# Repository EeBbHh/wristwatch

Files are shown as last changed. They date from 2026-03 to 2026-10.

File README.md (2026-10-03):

Disclaimer. This is a work in progress. Open source proof of concept provided. Screenshots and video provided. Documentation is subject to change.

NOTICE! Due to memory limits a second python file was created. sprites.py is required. Place next to code.py in the CIRCUITPY drive. The follwing lines need to be added to boot.py: "import displayio" and below that "displayio.release_displays()"

Clock + Metronome + Tuner wristwatch is the goal of this project. In addition. There are standalone files for each mode.

Dev Enviornment: Mu https://codewith.mu/en/, KiCAD https://www.kicad.org/

Circuitpython for QTpy RP2040: https://circuitpython.org/board/adafruit_qtpy_rp2040/

Circuitpython 10.x libraries: https://circuitpython.org/libraries

NOTE: Place the following in the lib folder: adafruit_bus_device folder, adafruit_display_text folder, adafruit_gc9a01a.mpy and adafruit_ticks.mpy. 

NOTE: Add the following to the requirements folder: adafruit_bus_device folder, adafruit_display_text folder and adafruit_gc9a01a folder.

Microcontroller: QTpy RP2040 https://www.adafruit.com/product/4900

Special thanks to these two projects that got me started on this journey. https://projecthub.arduino.cc/petbump10/arduino-tick-tock-metronome-a49188 and https://github.com/FoamyGuy/Adafruit_CircuitPython_Display_AnalogClock

Prototype 1, 2 and 3 Display: 1.28" Round TFT https://www.adafruit.com/product/6178 

Prototype 1 hardware: EYESPI BFF https://www.adafruit.com/product/5772, IoT Button BFF https://www.adafruit.com/product/5666, Vibration Mini Motor https://www.adafruit.com/product/1201, Piezo Buzzer https://www.adafruit.com/product/1740, LIPO Charger BFF https://www.adafruit.com/product/5397, 400mAh LIPO Battery https://www.adafruit.com/product/3898

Prototype 2 hardware: IoT Button BFF removed. Prototype board added. SMD parts replace THT parts. All SMD parts purchsed from https://www.digikey.com/ Buttons added. Piezo replaced with magnetic transducer. Schematic and board file provided. 

Prototype 3 hardware: EYESPI BFF removed. Prototype board updated. SMD FPC added. SMD vibration motor replaces THT vibration motor. 420mAh LIPO battery https://www.adafruit.com/product/4236 replaces 400mAh LIPO battery. 

Prototype 4 hardware: Prototype board updated. New 1.28 Display https://www.buydisplay.com/1-28-inch-tft-lcd-display-240x240-round-circle-screen-for-smart-watch, SMD FPC updated. QTpy dock added. Futher refinement is underway as I put protoboardV4 through testing.

Prototype 5 hardware: Circuit for display reset added. Circuit for backlight added. QTpy dock adjusted from 17.5mm to 18mm. Prototype board version 5 sits at 25mm. 

Prototype 6 hardware: Lipo BFF circuitry absorbed to further reduce height of the stack. Side actuated buttons replaced top actuated buttons but might try other types.  Final iteration for 6 will have the female headers removed and vibration motor moved out of the way for soldering the QTpy closer to the board. Prototype board version 6 sits at 11.30mm. Goal is to get closer to 13 with case.

Prototype 7 hardware: TBD

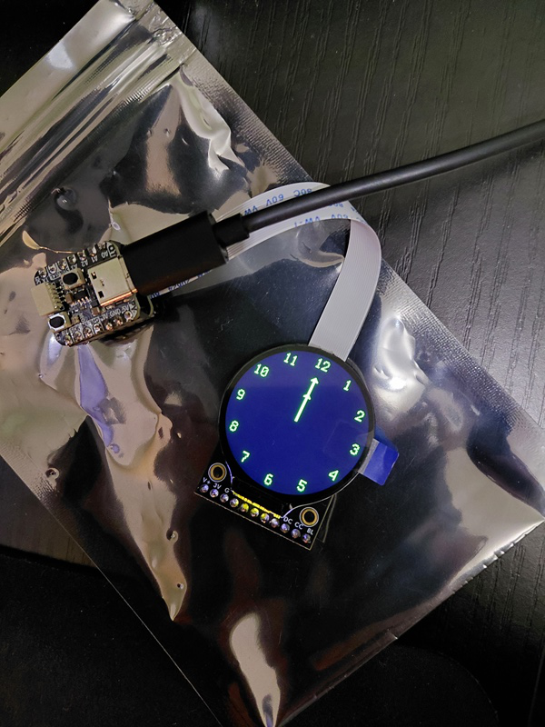
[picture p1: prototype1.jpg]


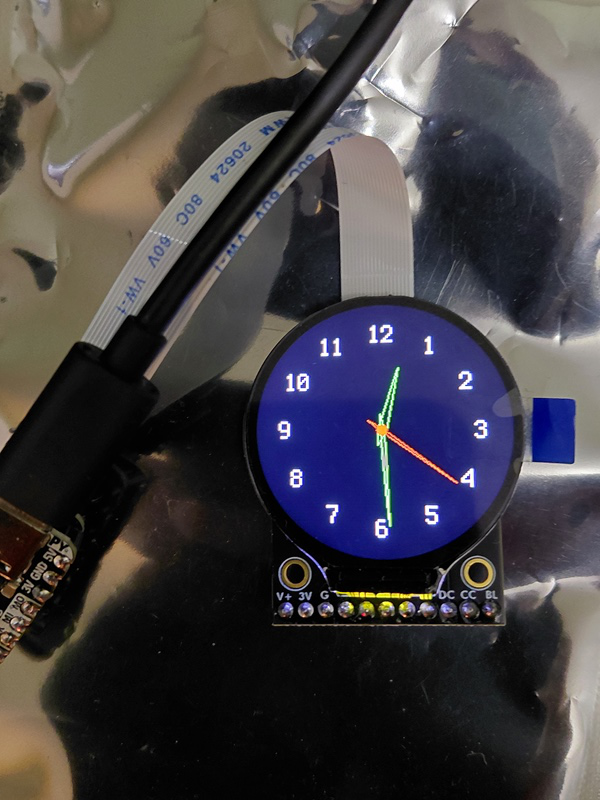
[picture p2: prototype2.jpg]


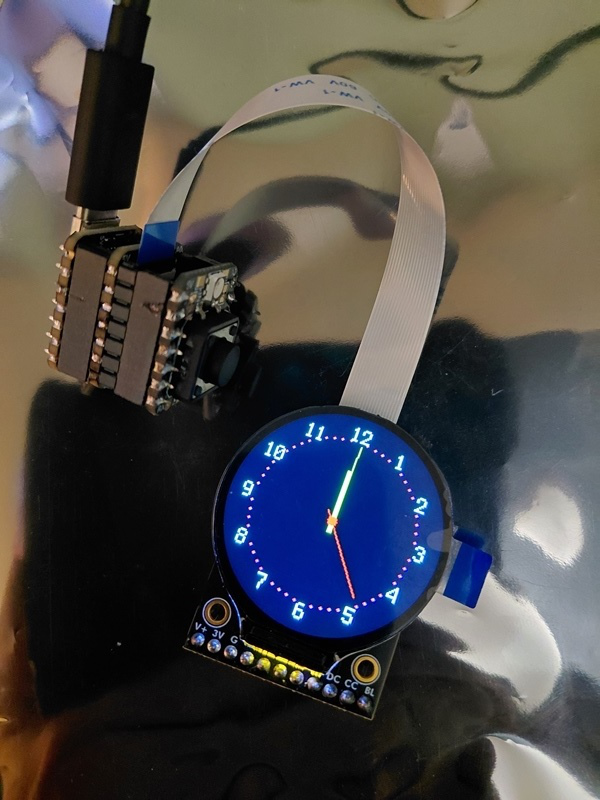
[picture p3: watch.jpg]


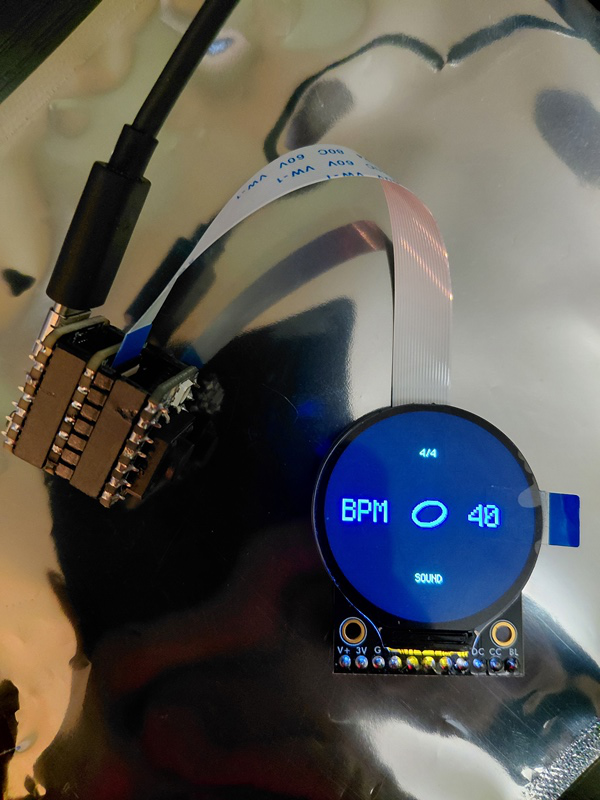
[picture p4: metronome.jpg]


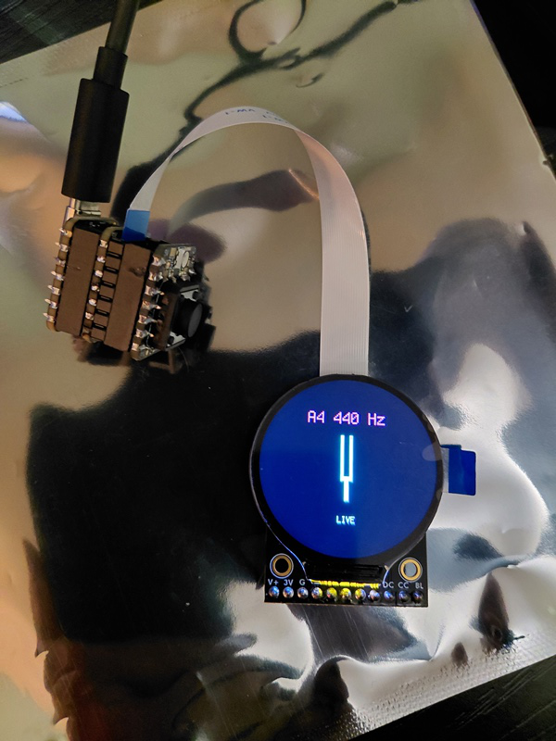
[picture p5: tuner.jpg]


https://github.com/user-attachments/assets/00a04122-98c7-4e2a-a195-a43d13c6c467

Vibration circuit layout. A transistor and resistor are used to make it possible for the QTpy to control the motor with 3 volts. A diode is used as a flyback for when the motor stops running. The transistor connects to the black wire, the resistor and the diode. The black wire goes from the emitter lead of the transistor to ground. The resistor(100ohm) connects the base lead of the transistor to A1. The anode portion of the diode connects to the collector lead of the transistor. The cathode porton of the diode connects to the red wire. The red wire connects to 3.3 volts. The driver motor connects to each side of the diode. Blue to anode and red to cathode. 

Component list: 100Ω resistor, diode(1N4007) and transistor(2N2222)

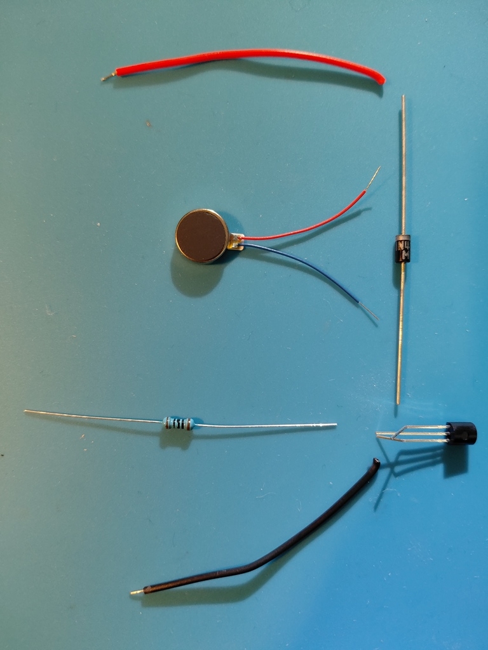
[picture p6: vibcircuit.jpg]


Soldered vibration circuit.

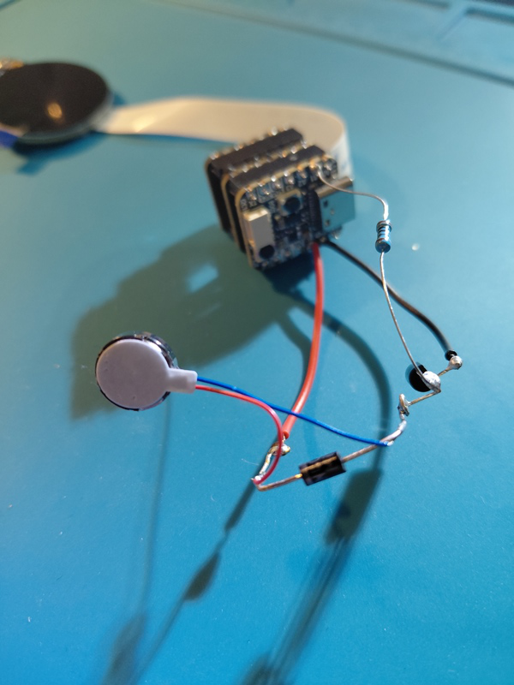
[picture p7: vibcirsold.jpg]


https://github.com/user-attachments/assets/0c229e03-611d-4f90-9194-24d2ad153cdb

Soldered piezo.

https://github.com/user-attachments/assets/ea14efcf-dfc6-47f1-8c45-b138b7211cc2

LIPO BFF added. Backlight hack added(red wire at the top) to allow for screen dimming as a battery saving feature.

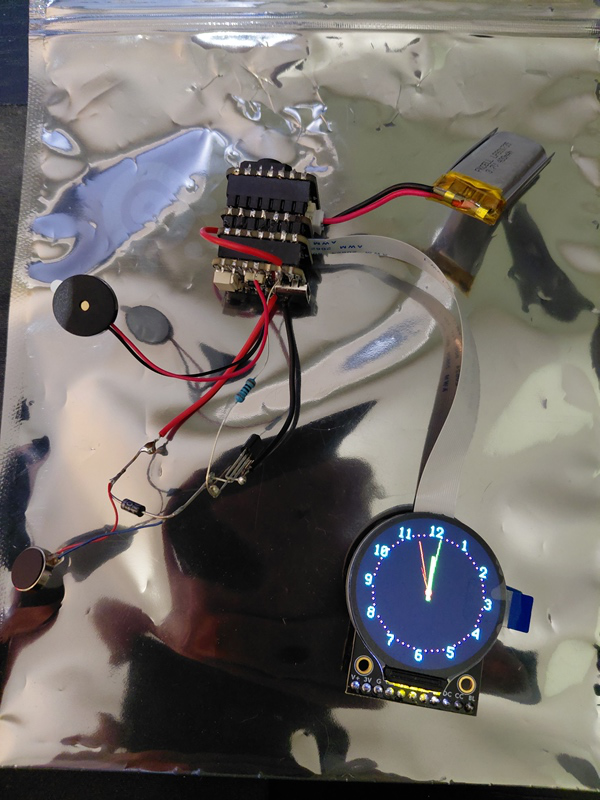
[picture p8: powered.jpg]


Screen dimming test. At the 10 second mark the screen dims.

https://github.com/user-attachments/assets/76fc044c-b8f3-486a-8c0e-50453308a22c

Prototype 2 board screenshots. Pre and post solder.

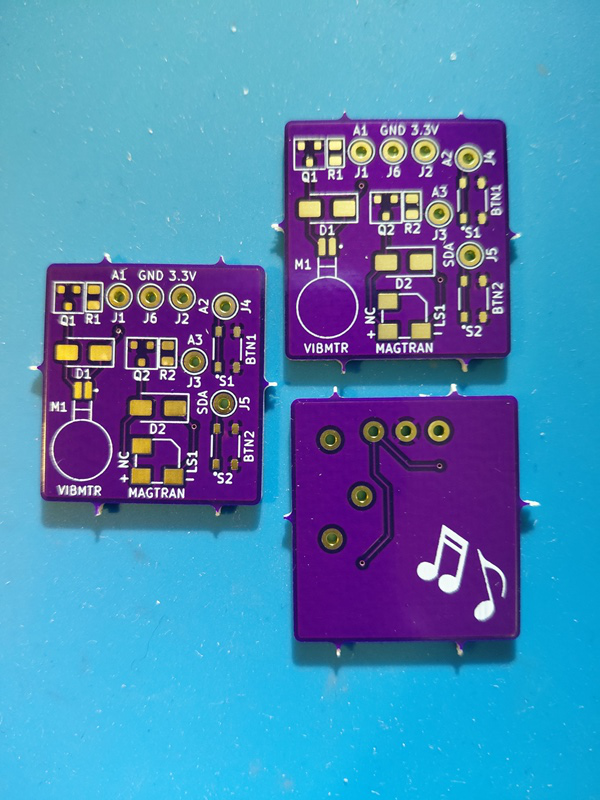
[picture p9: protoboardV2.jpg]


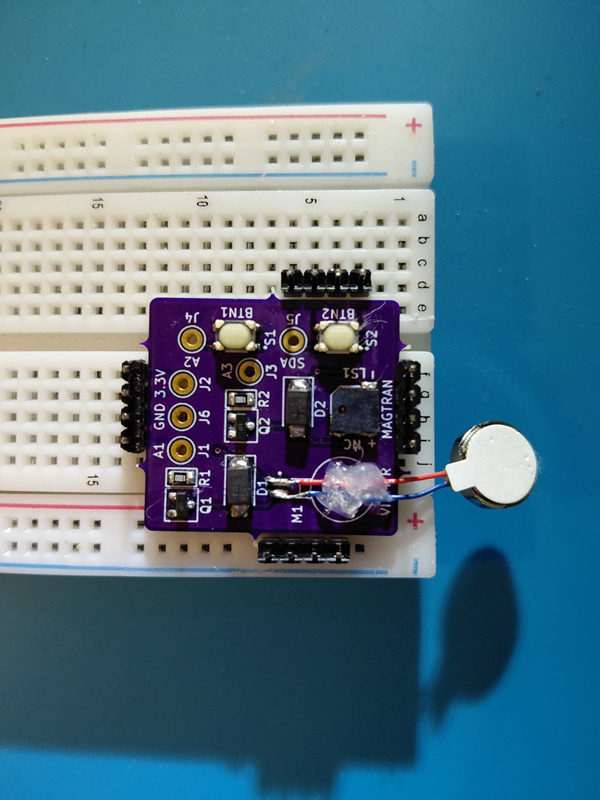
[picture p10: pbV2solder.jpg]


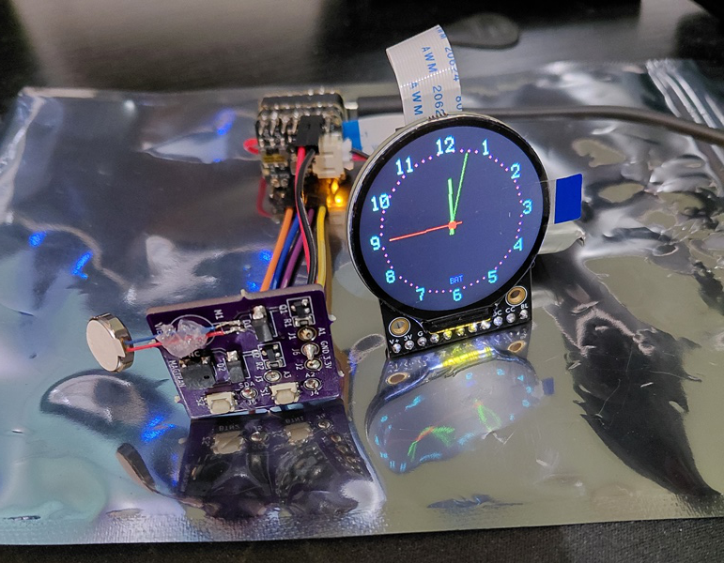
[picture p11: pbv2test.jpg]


Prototype 3 board screenshots. Pre and post solder.

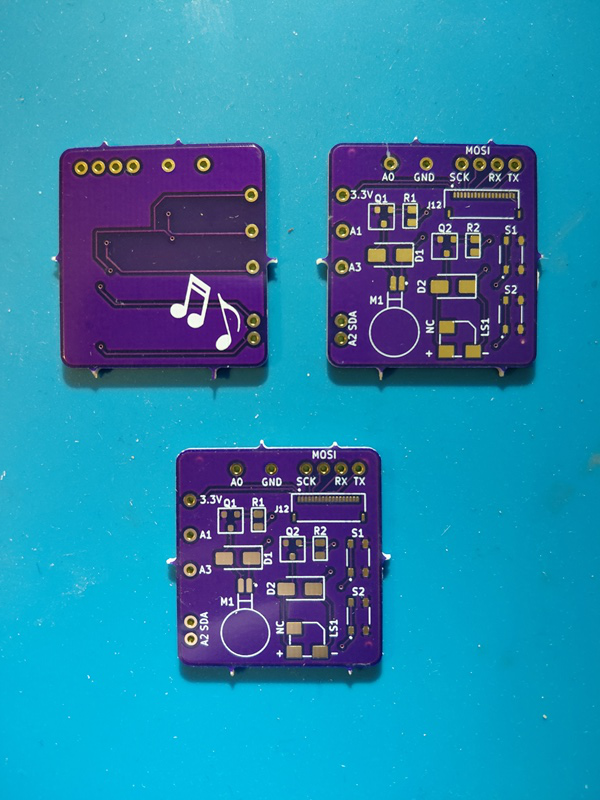
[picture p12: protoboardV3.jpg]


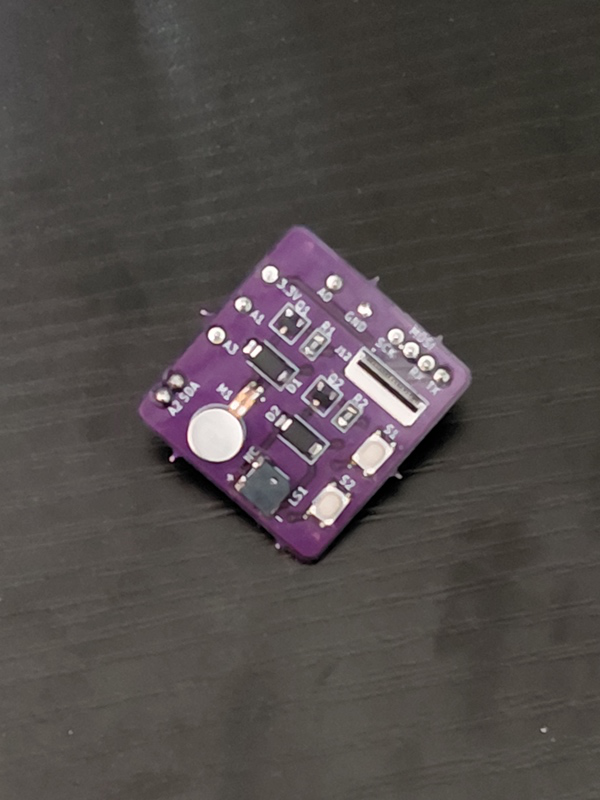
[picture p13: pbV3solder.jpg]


Prototype 4a board screenshots. Pre and post solder.

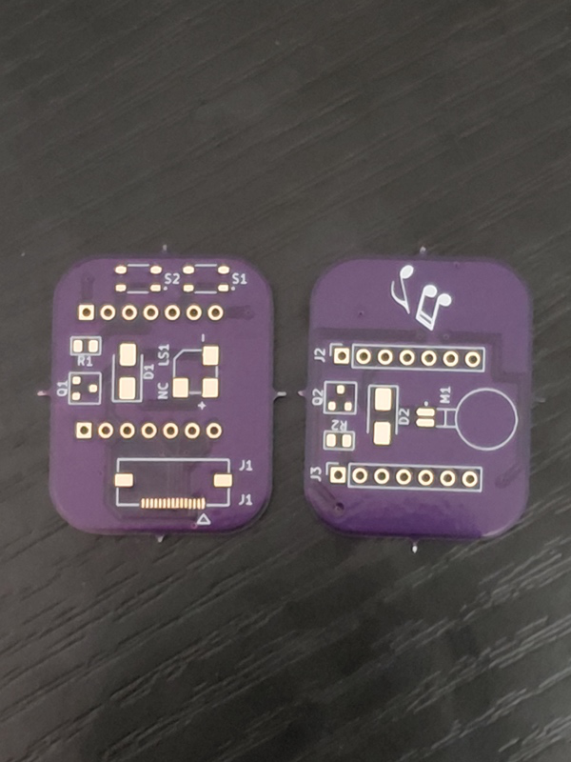
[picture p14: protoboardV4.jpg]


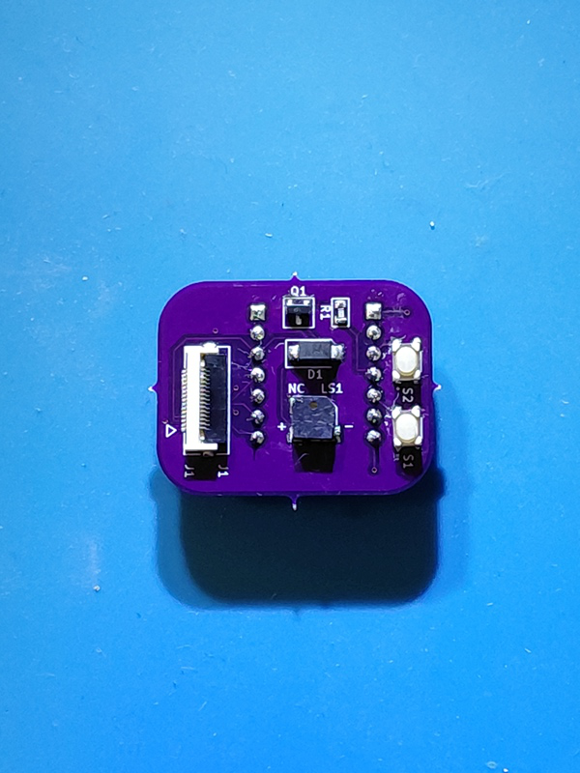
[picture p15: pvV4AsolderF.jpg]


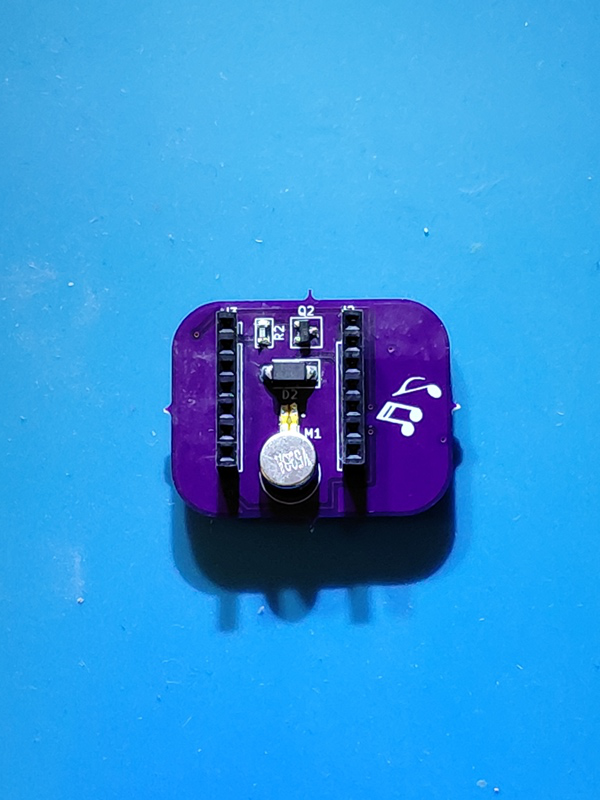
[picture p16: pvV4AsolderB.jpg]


Prototype 5a board screenshots. Pre and post solder.

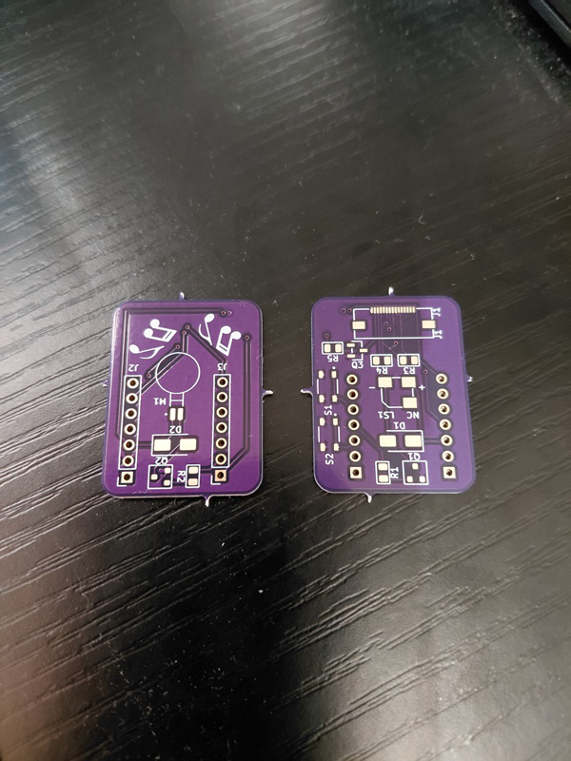
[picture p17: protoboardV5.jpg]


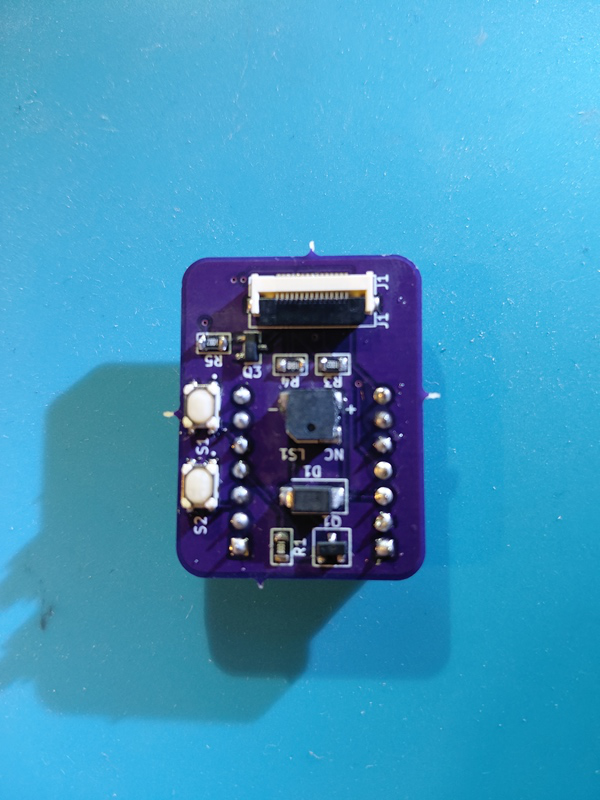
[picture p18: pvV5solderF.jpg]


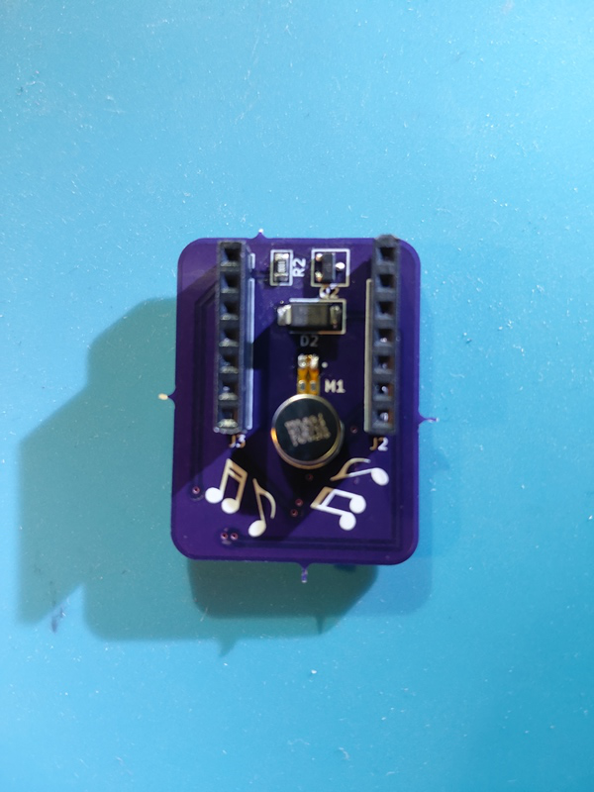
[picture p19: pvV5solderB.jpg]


Prototype 5b board screenshots. Pre and post solder.

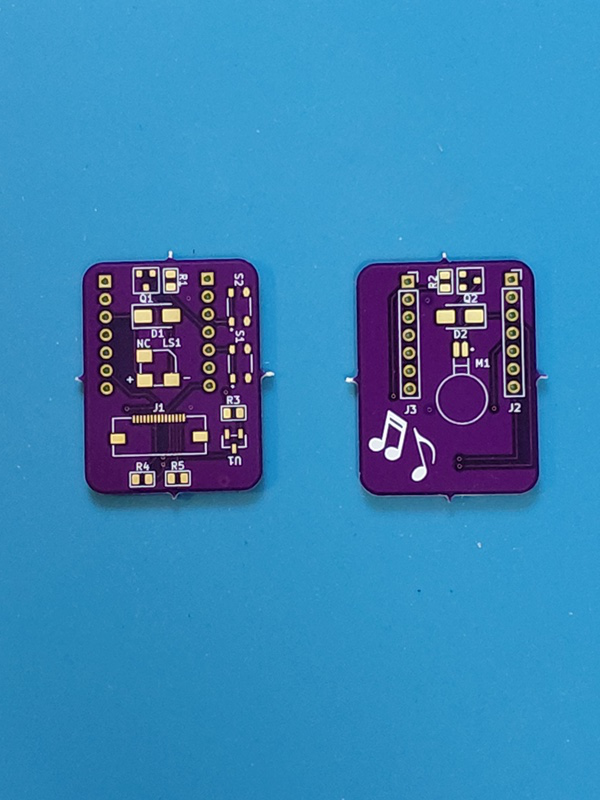
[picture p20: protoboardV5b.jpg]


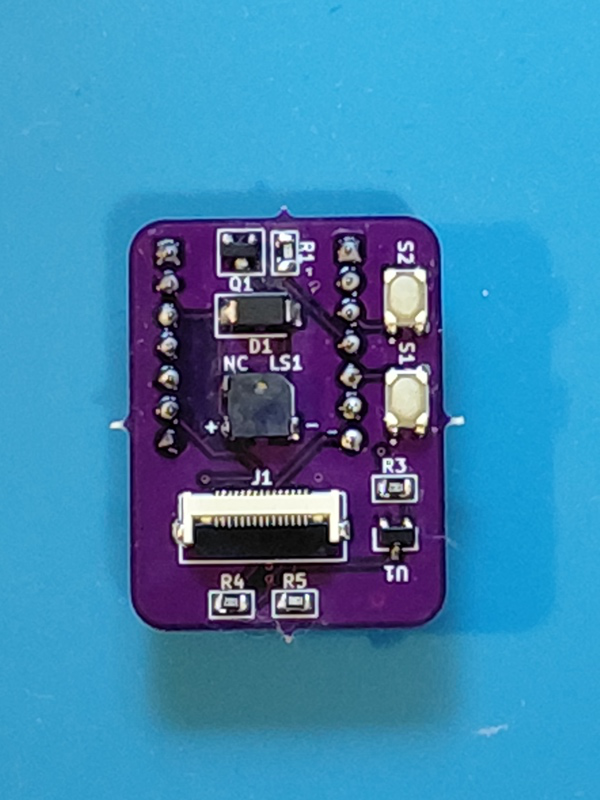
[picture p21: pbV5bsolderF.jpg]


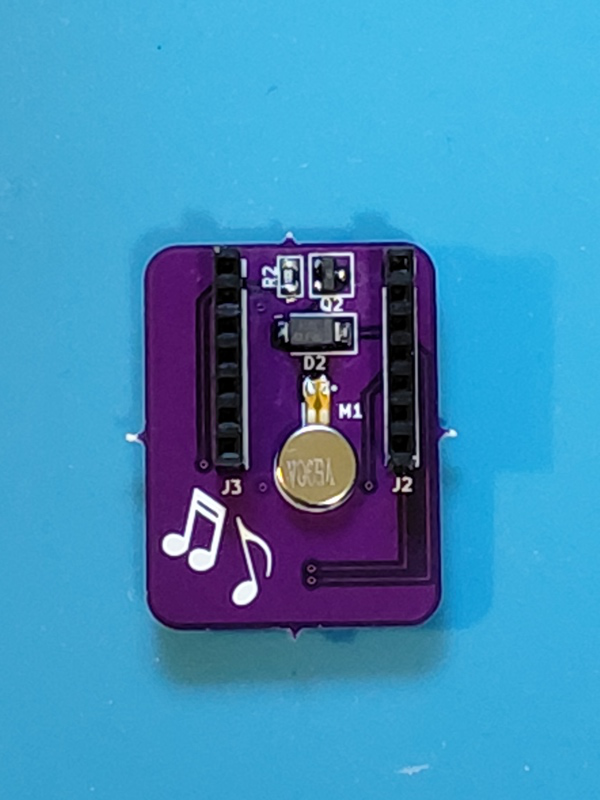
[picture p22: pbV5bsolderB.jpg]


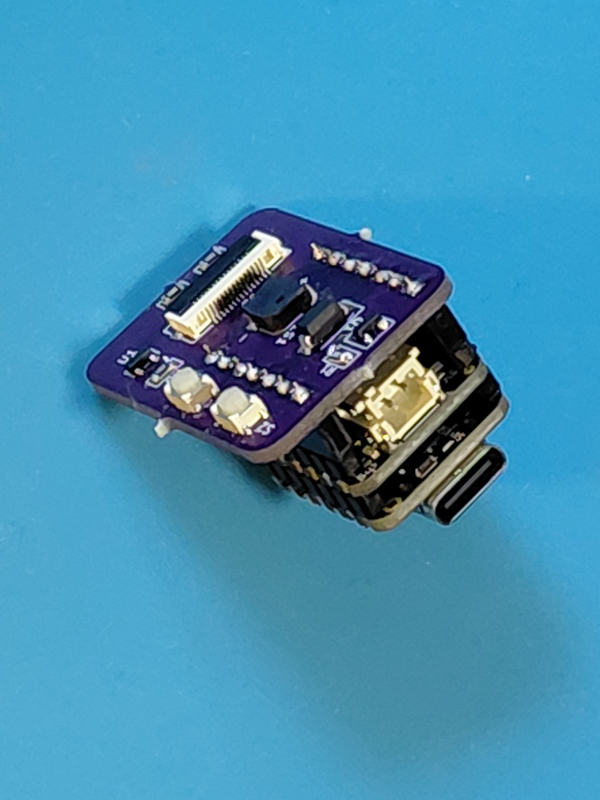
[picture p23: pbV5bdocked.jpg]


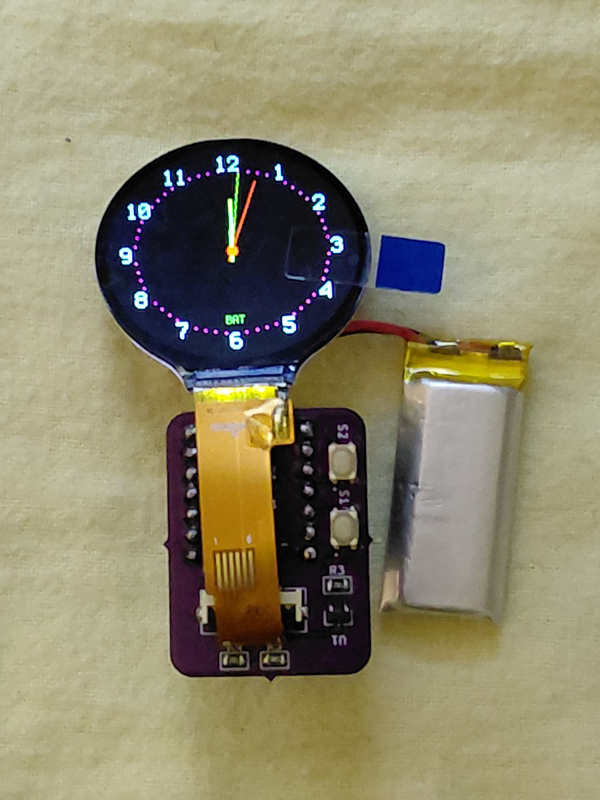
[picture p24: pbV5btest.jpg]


Prototype 6a board screenshots. Pre and post solder.

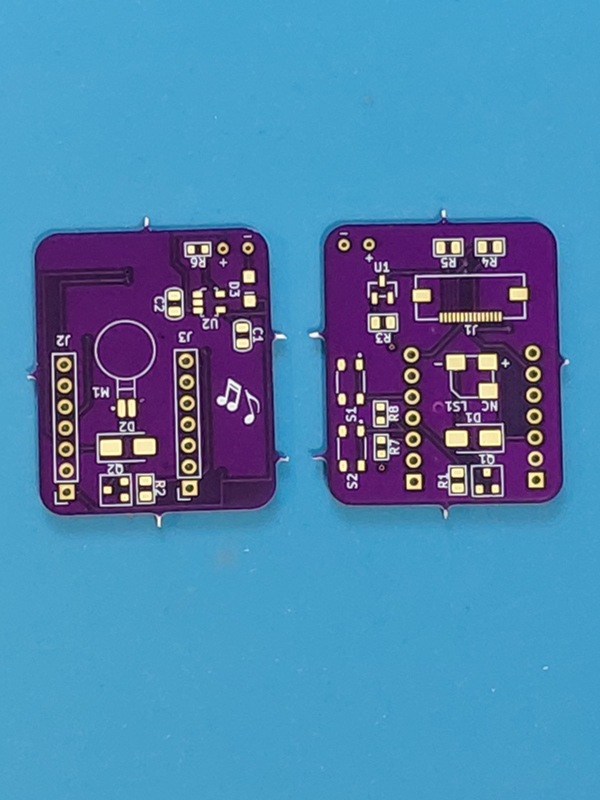
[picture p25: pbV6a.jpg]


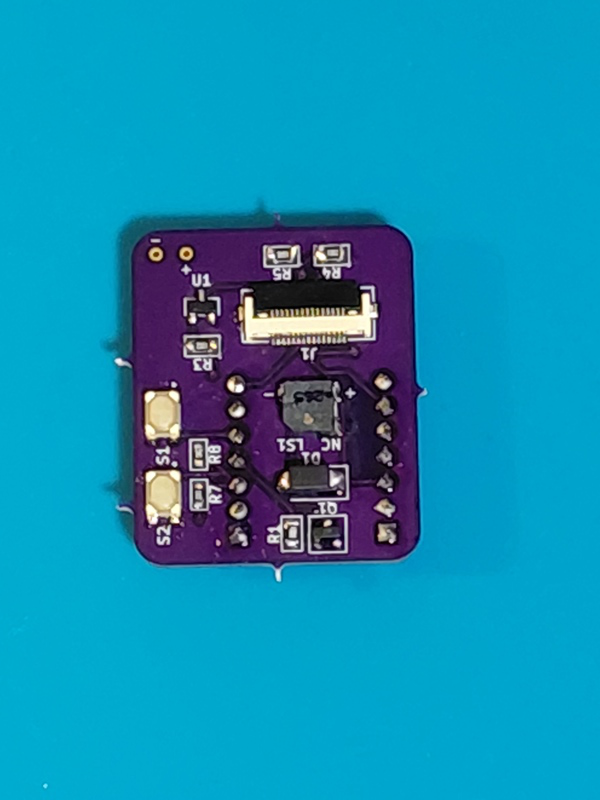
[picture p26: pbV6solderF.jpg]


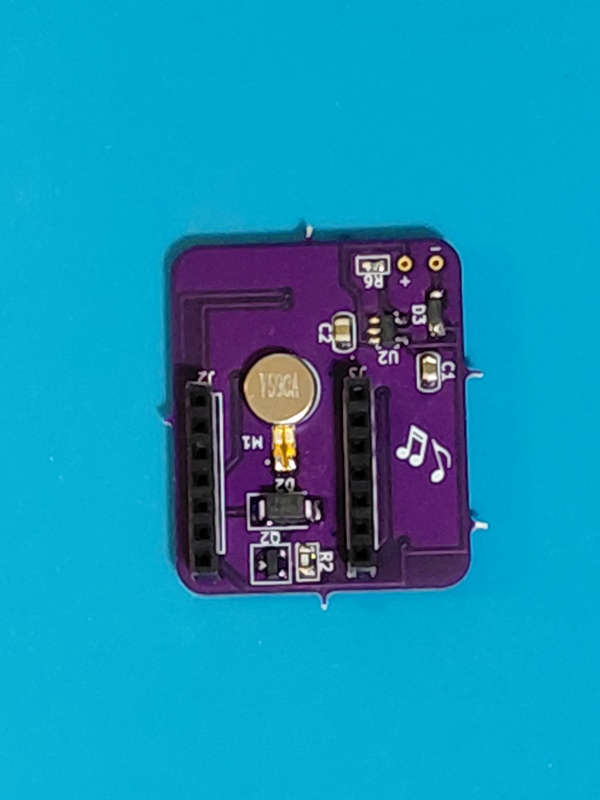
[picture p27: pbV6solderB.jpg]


Prototype 6b board screenshots. Pre and post solder.

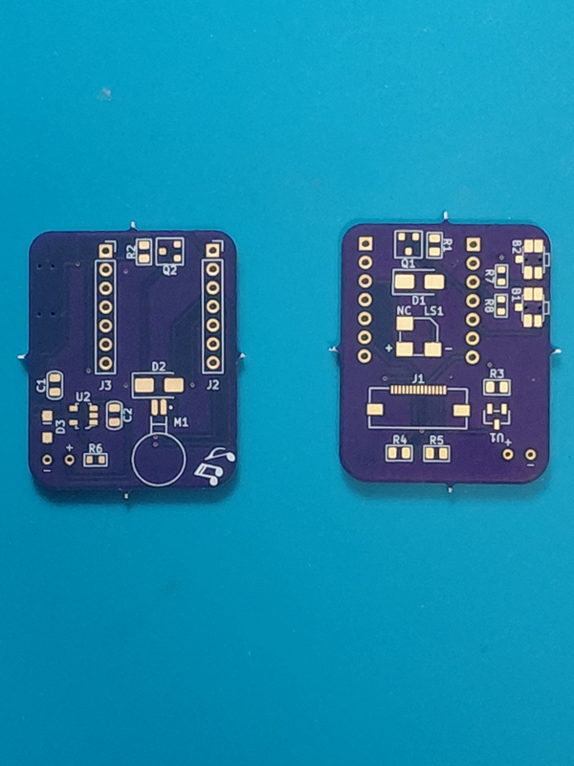
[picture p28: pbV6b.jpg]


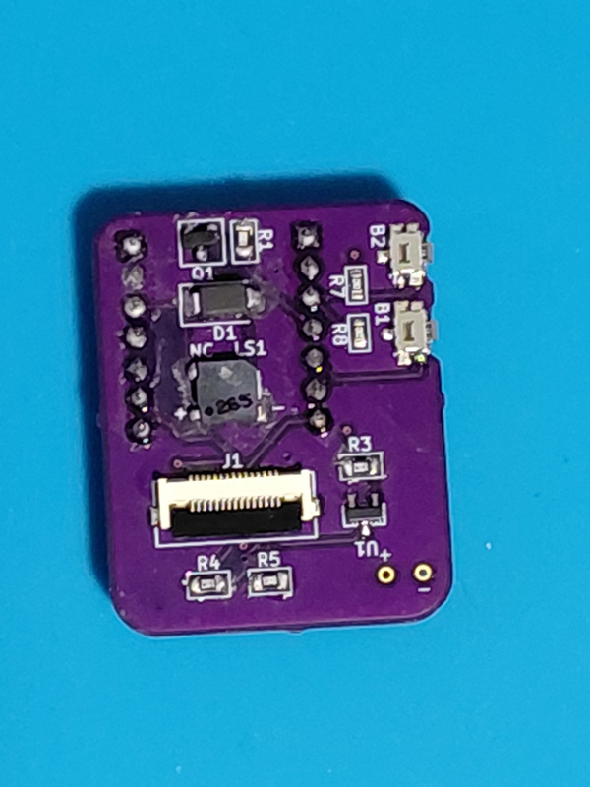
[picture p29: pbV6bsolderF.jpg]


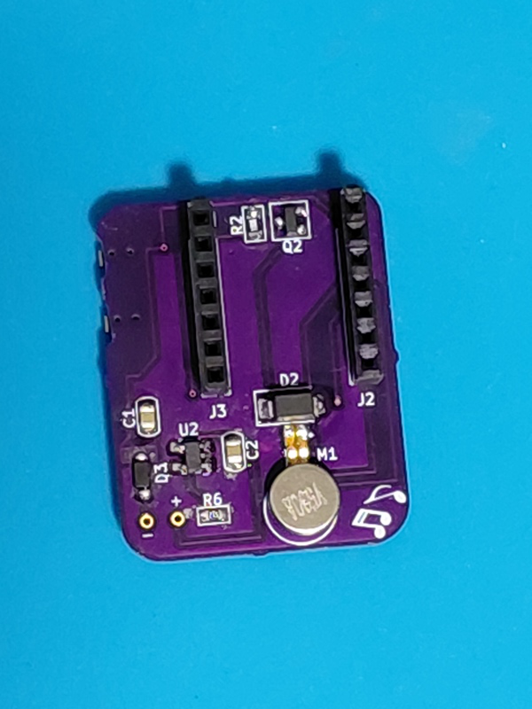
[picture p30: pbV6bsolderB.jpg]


Prototype 6c board screenshots. Pre and post solder.

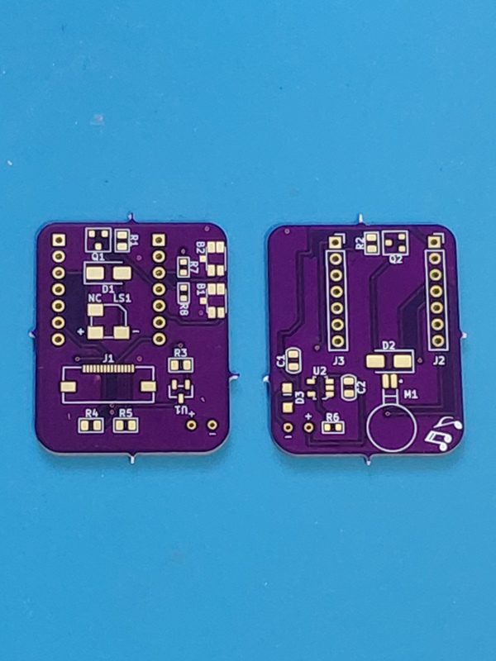
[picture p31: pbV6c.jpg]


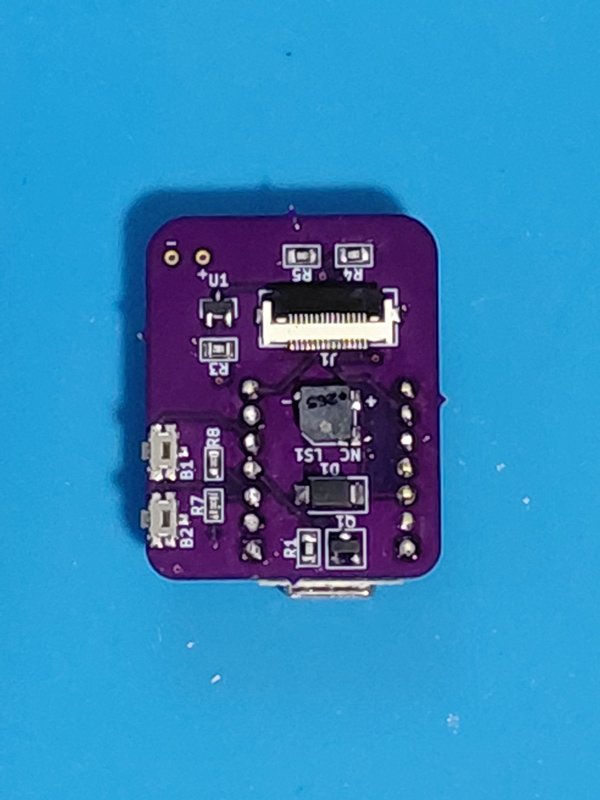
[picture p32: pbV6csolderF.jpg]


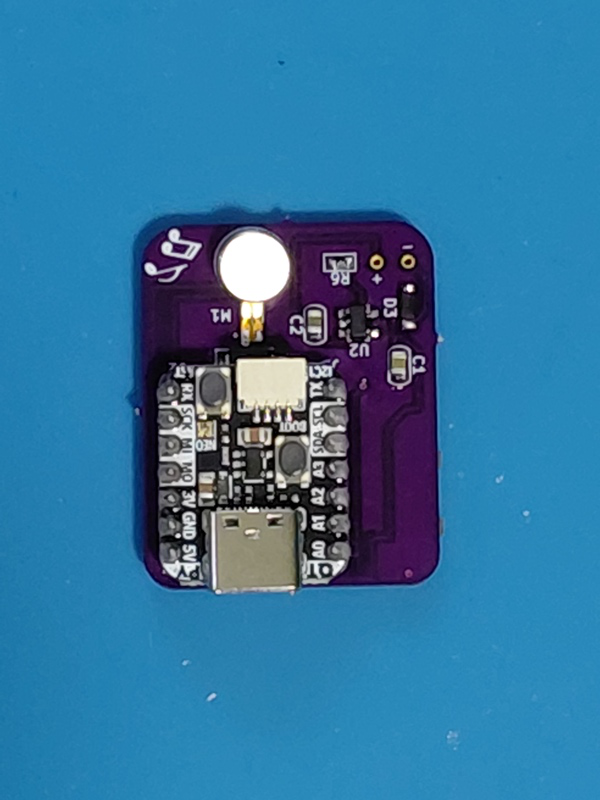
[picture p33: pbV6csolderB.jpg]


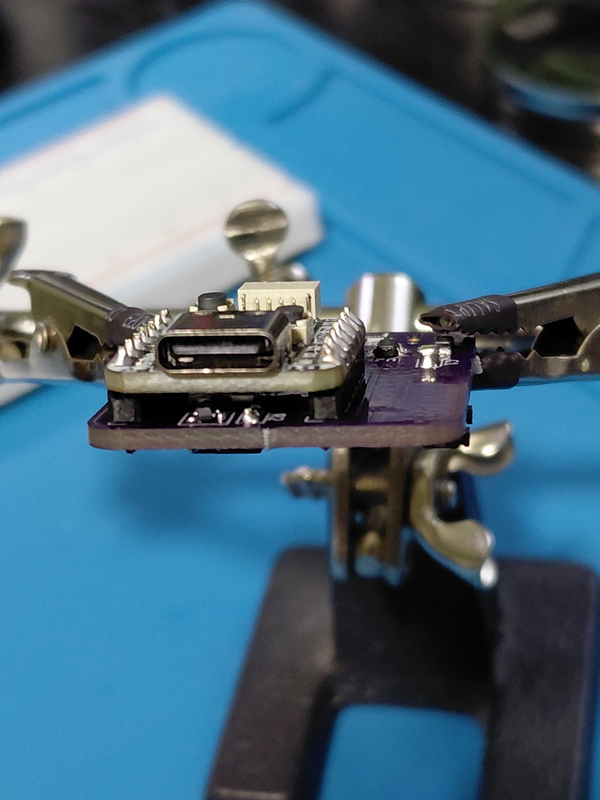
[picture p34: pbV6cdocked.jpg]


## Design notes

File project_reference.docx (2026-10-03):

Wristwatch Project Reference

CircuitPython Multi-Mode Watch on Adafruit QT Py RP2040

# 1. Project Overview

A round-face wristwatch built on an Adafruit QT Py RP2040 and a custom carrier PCB. The watch supports three modes — Clock, Metronome, and Tuner — displayed on a 240×240 GC9A01A round LCD. Hardware feedback is provided by a passive buzzer and a vibration motor. Power comes from a 3.7 V LiPo cell managed by an MCP73831T charge controller absorbed onto the carrier board.

## 1.1 Modes

Mode | Entry Gesture | Description
Clock | Both buttons held 0.3 s → release | Analog watch face with hour, minute, second hands. BOOT sets time; A2 increments field.
Metronome | Both buttons held 0.3 s → release | Animated note sprite fades in/out on each beat. A2 raises BPM; BOOT lowers BPM. Long-press A2 cycles time signature (4/4, 3/4). Long-press BOOT toggles silent mode (motor pulses instead of buzzer).
Tuner | Both buttons held 0.3 s → release | Tuning fork graphic. A2 cycles through guitar reference pitches (E4–E6). BOOT strikes the note (3 s tone); press BOOT again to stop early.

# 2. Hardware

## 2.1 Prototype 1 — Breadboard

Initial proof-of-concept assembled on a breadboard using a QT Py RP2040, GC9A01A breakout, and passive components. Established SPI wiring, button pull-up behaviour, and basic CircuitPython displayio architecture.

## 2.2 SMD Revision History

Revision | Key Changes | Outcome
SMDv1–v4 | Initial PCB iterations; hand-soldered SMD components. | Early layout and routing learning. Functional display and button wiring.
SMDv5a | Added MCP73831T charge controller and LiPo connector. Battery voltage divider (R1+R3) on A2. | Charge controller integrated on carrier; battery monitoring enabled.
SMDv6 | Refined BFF connector layout. MMBT2222A NPN transistors for motor (Q2) and buzzer (Q1). SS14 flyback diode (D2). MBR120 reverse-polarity diode (D3). Working board — used as reference. | First fully working board with motor and buzzer circuits.
SMDv7 | Attempted B.Cu mirror corrections for D2 and M1 — OVER-CORRECTED. Motor ran constantly on power-up. | Hardware defect board. Identified over-correction error.
SMDv8 | Reverted D2 and M1 to SMDv6 orientation. D3 rotated 180° (correct per schematic net verification). New SKSCPCE010 buttons without alignment pegs. FPC display connector. | Display working. Motor still runs constantly (residual B.Cu hardware issue on this physical unit). Battery contact issue diagnosed. 11.30 mm stack thickness achieved.

## 2.3 GPIO Pin Allocation

Pin | Net / Signal | Direction | Notes
SCK | SPI Clock | OUT | Display SPI clock
MOSI | SPI MOSI | OUT | Display SPI data
TX | Display CS | OUT | Chip-select for GC9A01A
RX | Display D/C | OUT | Data/Command select
A0 | Backlight PWM | OUT | PWM brightness control; full on boot
A1 | Motor PWM | OUT | PWMOut 1 kHz; MOTOR_STRENGTH = 49151 (75%)
A2 | Button / ADC | IN/ADC | Pull-up input; time-shared with battery ADC
A3 | Buzzer PWM | OUT | variable_frequency PWMOut; BUZZER_DUTY = 32768
SDA | BOOT button | IN | Pull-up; mode cycle and time-set

## 2.4 Vibration Motor Circuit

The vibration motor is driven by an MMBT2222A NPN transistor (Q2) on the B.Cu layer. The correct circuit topology, as verified in SMDv6 and confirmed in the SMDv8 schematic, is:

- Q2 Base → R2 (current-limiting resistor) → A1 (PWM output)
- Q2 Collector → Motor V− junction (motor negative terminal and SS14 anode)
- Q2 Emitter → GND
- Motor V+ → +3.3 V
- SS14 Flyback Diode D2: Cathode → +3.3 V, Anode → Q2 Collector / Motor V− junction

This is the correct and verified layout. The SMDv7 over-correction (which swapped D2 and M1 orientation) caused the motor to run constantly on power-up. Both components were reverted to the SMDv6 orientation in the SMDv8 schematic. The SMDv8 physical board has the motor running constantly due to an error in the fabricated board — the next revision should be correct.

In code.py, motor control uses PWM:

motor = pwmio.PWMOut(board.A1, frequency=1000, duty_cycle=0)

MOTOR_STRENGTH = 49151 # 75% duty cycle

def vibrate(ms):

motor.duty_cycle = MOTOR_ON

time.sleep(ms / 1000)

motor.duty_cycle = MOTOR_OFF

## 2.5 Buzzer Circuit

A passive buzzer is driven by an MMBT2222A NPN transistor (Q1) on the F.Cu layer. The buzzer uses variable-frequency PWM:

buzzer = pwmio.PWMOut(board.A3, variable_frequency=True)

buzzer.frequency = 440

BUZZER_DUTY = 32768 # 50% square wave

Tone generation:

def tone(freq, ms):

buzzer.frequency = freq

buzzer.duty_cycle = BUZZER_DUTY

time.sleep(ms / 1000)

buzzer.duty_cycle = 0

## 2.6 MBR120 Reverse-Polarity Protection (D3)

D3 is an MBR120 Schottky diode providing reverse-polarity protection on the battery input. It resides on B.Cu. The correct orientation (verified SMDv8):

- D3 Pin 1 (Cathode) → J6 (battery pad)
- D3 Pin 2 (Anode) → junction of C1 and +5 V rail

Important: when net assignments were swapped for D3 in the schematic, the silkscreen cathode marker did NOT update automatically. The working position was determined by testing with the physical board and confirmed against schematic net names and the KiCad 3D viewer — NOT the silkscreen. Always verify diode orientation against schematic net names, not silkscreen markings.

## 2.7 MCP73831T LiPo Charge Controller

The MCP73831T charge controller is absorbed onto the carrier PCB (not a separate BFF module). Key connections:

Pin | Net | Notes
1 (VBATT) | +VBAT junction | Battery positive; connects to D2 anode and motor V+ rail
2 (VSS) | GND | Ground
3 (PROG) | No connect | Charge current programming resistor not fitted (default rate)
4 (STAT) | Net VDD | Status output
5 (+5V) | +5 V rail | USB power input

## 2.8 Battery and Power

Battery: 3.7 V LiPo. The battery voltage divider uses R1 and R3 (100 kΩ each) connected to A2. VDIV factor = 2.0. Charging threshold: CHARGE_V = 4.3 V.

Battery ADC read in code.py:

def read_battery():

# A2 is time-shared: deinit as digital, read as ADC, reinit as digital

btn_a2.deinit()

adc = analogio.AnalogIn(board.A2)

raw = adc.value

adc.deinit()

btn_a2 = digitalio.DigitalInOut(board.A2)

btn_a2.direction = digitalio.Direction.INPUT

btn_a2.pull = digitalio.Pull.UP

return (raw / 65535) * 3.3 * 2.0 # VDIV = 2.0

Battery status labels appear at the bottom of all three mode screens. Colour coding: Green ≥ 50%, Yellow ≥ 25%, Red < 25%, Blue = charging.

## 2.9 Display

GC9A01A 240×240 round LCD connected via SPI. SPI baud rate: 24 MHz. Backlight controlled via A0 PWM (BL_FULL = 65535, BL_DIM = 16384). Display dims after 300 seconds of inactivity.

Boot sequence (memory critical):

- gc.collect() → core imports → release_displays → allocate shared_bitmap(240,240,24) → import pwmio + init backlight → init display driver → remaining inits

## 2.10 Buttons

Two buttons are used:

Button | Pin | Role
BOOT (onboard) | SDA | Mode cycle (both-hold), time set (Clock), BPM decrease (Metro), tuner strike (Tuner)
A2 (external) | A2 | Time-set increment (Clock), BPM increase (Metro), note cycle (Tuner)

Both pulled HIGH internally; active LOW when pressed.

Button revision history:

- SMDv6: SKSCPCE010 side-actuated SMD buttons — worked on breadboard prototype; insufficient actuator length on carrier due to 5 mm display overhang on three sides.
- SMDv8: SKSCPCE010 without alignment pegs (new variant). Buttons sit on board edge but actuators still too short; one actuator melted/broke during soldering due to proximity to iron.
- Current plan: Return to top-actuated SMD buttons. Design case-integrated angled pushers in TinkerCAD (similar to commercial smartwatch membrane approach). Rubber membrane or button cap extensions to bridge the display overhang gap.
- MJTP1117 through-hole right-angle buttons evaluated (7.30 × 6.80 mm body) — too large for the current PCB footprint.

## 2.11 B.Cu Mirror Corrections (SMDv8)

Components on the back copper layer (B.Cu) are physically mirrored left-to-right in the fabricated board. Correction rules:

- SOT-23 / SOT-23-5 packages: always verify pin swap — asymmetric pin layout means a pin-for-pin swap is required.
- Two-terminal components (diodes, motor): do NOT apply universal mirror correction — verify each component individually against schematic net names and the KiCad 3D viewer.

Component | Rev | Action | Result
D2 (SS14 flyback) | SMDv7 | Over-corrected (swapped) — ERROR | Motor ran constantly; reverted in SMDv8
M1 (vibration motor) | SMDv7 | Over-corrected (swapped) — ERROR | Motor ran constantly; reverted in SMDv8
D2 (SS14 flyback) | SMDv8 | Reverted to SMDv6 orientation | Correct per schematic
M1 (vibration motor) | SMDv8 | Reverted to SMDv6 orientation | Correct per schematic
D3 (MBR120 reverse-polarity) | SMDv8 | Rotated 180° — verified correct | Board powers from battery in this orientation
U2 (MCP73831T) | SMDv8 | Confirmed correct (SOT-23-5 pins verified) | No change needed
Q2 (MMBT2222A motor transistor) | SMDv8 | Confirmed correct (SOT-23 pin swap verified) | No change needed

## 2.12 Stack Thickness

SMDv8 measured stack thickness: 11.30 mm (PCB + components + display assembly). Target for wearable form factor.

# 3. CIRCUITPY Drive Layout

File | Description
code.py | Main program — boot, display, all three modes, button handling, battery monitoring
sprites.py | Note sprite pixel buffer builders for metronome mode; imported by code.py after shared_bitmap allocation
boot.py | USB drive and serial configuration (if present)

Required libraries (from Adafruit CircuitPython Bundle):

- adafruit_gc9a01a
- adafruit_display_text (bitmap_label, label)

# 4. Code Walkthrough

## 4.1 code.py

### Boot Sequence and Memory Management

Memory is critically limited on RP2040 with CircuitPython. The boot sequence is ordered to minimise peak allocation:

import gc

gc.collect()

# Core imports first — before any display allocation

import board, busio, displayio, fourwire, adafruit_gc9a01a

import vectorio, bitmaptools, terminalio, digitalio, rtc

import time, math

from adafruit_display_text.bitmap_label import Label

from adafruit_display_text import label

gc.collect()

displayio.release_displays()

gc.collect()

# Allocate shared bitmap BEFORE pwmio — largest single allocation

shared_bitmap = displayio.Bitmap(240, 240, 24) # 57,600 bytes

shared_bitmap.fill(0)

# Now safe to init PWM and display

import pwmio

backlight = pwmio.PWMOut(board.A0, frequency=1000, duty_cycle=65535)

The shared_bitmap (57,600 bytes) is the largest allocation. It is shared between clock_tilegrid and metro_tilegrid with different palettes — this avoids allocating two separate bitmaps.

### Display Initialisation

spi = busio.SPI(clock=board.SCK, MOSI=board.MOSI)

display_bus = fourwire.FourWire(

spi, command=board.RX, chip_select=board.TX,

reset=None, baudrate=24_000_000

)

display = adafruit_gc9a01a.GC9A01A(

display_bus, width=240, height=240, rotation=0, auto_refresh=False

)

auto_refresh=False is important — the code calls display.refresh() explicitly to control when frames update, which prevents partial-frame visual artefacts in the metronome animation.

### Button Initialisation

btn_a2 = digitalio.DigitalInOut(board.A2)

btn_a2.direction = digitalio.Direction.INPUT

btn_a2.pull = digitalio.Pull.UP

btn_boot = digitalio.DigitalInOut(board.SDA)

btn_boot.direction = digitalio.Direction.INPUT

btn_boot.pull = digitalio.Pull.UP

A2 is later deinit/reinit as an ADC for battery reading. The SDA pin is used for the onboard BOOT button.

### Motor and Buzzer Initialisation

motor = pwmio.PWMOut(board.A1, frequency=1000, duty_cycle=0)

MOTOR_STRENGTH = 49151 # 75% duty cycle (65535 * 0.75)

buzzer = pwmio.PWMOut(board.A3, variable_frequency=True)

buzzer.frequency = 440

BUZZER_DUTY = 32768 # 50% square wave

Motor starts with duty_cycle=0 (off). MOTOR_STRENGTH is set to 75% for adequate vibration without excessive current draw.

### Timing and BPM Constants

BPM_START = 80

BPM_MIN = 40

BPM_MAX = 250

BPM_STEP = 5

REFRESH_FLOOR = 0.065 # Minimum time between display refreshes (seconds)

MAX_FADE = max(1, int((60.0 / BPM_MIN) / REFRESH_FLOOR))

MAX_FADE determines the maximum number of fade steps in the metronome palette. At BPM_MIN=40, one beat cycle is 1.5 s; divided by REFRESH_FLOOR gives the maximum steps the display can show in one beat.

### Palette Architecture

Three palettes share the same NUM_COLOURS size (MAX_FADE + 1):

- clock_palette: index 0 = transparent (0xFF00FF), 1 = green (hands), 2 = red (second hand / centre dot), 3+ = black (unused slots)
- metro_palette: index 0 = black (background), 1..FADE_STEPS = interpolated beat colour fading to black

clock_palette = displayio.Palette(NUM_COLOURS)

clock_palette[CLK_BG] = 0xFF00FF # transparent

clock_palette[CLK_GREEN] = 0x00FF00

clock_palette[CLK_RED] = COLOR_RED

clock_palette.make_transparent(CLK_BG)

### Clock Face Construction

The clock dial is built once at boot as a displayio.Group:

- Black filled circle (radius 120) as background
- 48 small pink-purple dots at minute positions (skipping every 5th for hour markers)
- 12 cyan number labels (1–12) at hour positions — scale=2 (terminalio.FONT)
- set_label: small cyan text centred at y=175, shown only during time-set

Hand drawing uses bitmaptools.draw_line() on shared_bitmap with a half-width loop to create thick hands:

def draw_hand(bmp, x0, y0, x1, y1, col, hw):

# hw = half-width in pixels

dx, dy = x1-x0, y1-y0

length = math.sqrt(dx*dx + dy*dy)

px, py = -dy/length, dx/length # perpendicular unit vector

for d in range(-hw, hw+1):

ox, oy = int(d*px), int(d*py)

bitmaptools.draw_line(bmp, x0+ox, y0+oy, x1+ox, y1+oy, col)

Hand widths: hour = 2, minute = 1, second = 0 (single pixel).

### Metronome BPM Colour Gradient

BPM maps to a colour via a 12-stop gradient (GRADIENT constant). Intermediate colours are linearly interpolated. The active colour is also applied to the BPM number and note label.

Note sprite selection by BPM range (RANGES constant):

BPM Range | Note Symbol
40–59 | Whole note
60–79 | Half note
80–119 | Quarter note
120–159 | Eighth note
160–199 | Beamed eighth notes
200–250 | Sixteenth note

### Metronome Beat Loop

The beat loop uses precise timing to step through fade frames:

target_time = beat_start + (step_num + 1) / (FADE_STEPS + 1) * cycle_s

remainder = target_time - time.monotonic()

if remainder > 0: time.sleep(remainder)

step -= 1

if step < 0:

step = FADE_STEPS

beat_start += cycle_s

is_downbeat = (metro_beat_pos == 0)

if not metro_silent:

tone(880 if is_downbeat else 660, 60)

else:

vibrate(80 if is_downbeat else 50)

metro_beat_pos = (metro_beat_pos + 1) % TIME_SIG_BEATS[metro_ts_idx]

### Mode Switching

Both buttons held for BOTH_HOLD_S (0.3 s) then released triggers advance_mode(). Modes cycle: Clock → Metro → Tuner → Clock. The both_held() check runs at the top of every main loop iteration.

### Time-Set UI

During Clock mode, pressing BOOT triggers run_time_set():

- Loop over FIELDS = ('HOUR', 'MIN')
- set_label shows the current field name at y=175
- A2 increments the field; BOOT advances to the next field
- Both-hold during time-set exits without saving
- On completion, clock_rtc.datetime is updated

### Battery Monitoring

Battery is checked every BATT_CHECK_S (60 seconds). A2 is temporarily deinit as digital and reinit as ADC to take the reading, then restored to digital. The voltage is calculated with VDIV=2.0. Charge detection: voltage ≥ CHARGE_V (4.3 V). Battery percentage mapped linearly from 3.0 V (0%) to 4.2 V (100%).

### Display Dimming

After DIM_AFTER_S (300 s) of no button activity, backlight drops to BL_DIM (16384, ~25%). Any button press restores BL_FULL (65535) and clears display_dimmed. If a button press occurs while dimmed (is_waking()), it only wakes the display — it does not trigger its normal action.

### Tuner Mode

The tuning fork graphic is built by _build_tuner_group() and stored as tuner_group. The fork shape uses vectorio.Rectangle primitives. Three pairs of dashes (vectorio.Rectangle, colour-toggled via p_flash palette) flash when a note strikes.

Reference pitches (TUNER_NOTES):

String | Note | Frequency
Low E | E4 | 329.63 Hz
A | A4 | 440.00 Hz
D | D5 | 587.33 Hz
G | G5 | 783.99 Hz
B | B5 | 987.77 Hz
High E | E6 | 1318.51 Hz

TUNER_ON_S = 3.0 s tone duration. TUNER_FLASH_S = 0.4 s visual flash duration.

## 4.2 sprites.py

sprites.py is imported by code.py after shared_bitmap is allocated. It is immediately deleted from the module cache after build_sprites() runs to free memory:

import sprites as _spr; gc.collect()

SPRITE = _spr.build_sprites(); del _spr; gc.collect()

All sprite shapes are stored as bytearray pixel coordinate pairs (x, y, x, y, ...). This format allows efficient pixel-setting on shared_bitmap without iterating a 2D region.

### Sprite Primitive Functions

Function | Description
filled_ellipse(cx, cy, rx, ry, ang) | Solid rotated ellipse. Used for note heads.
outline_ellipse(cx, cy, rx, ry, ang, thickness) | Hollow rotated ellipse. Used for whole and half note heads.
thick_vline(x, y0, y1, w) | Thick vertical line. Used for note stems.
filled_rect(x, y, w, h) | Filled rectangle. Used for note beams.
bezier_flag(x0, y0, steps, thickness) | Cubic Bezier curve. Used for eighth note flag.
merge(*bufs) | Concatenates multiple pixel buffers into one bytearray.

### Note Sprites Built

Key | Construction
whole | outline_ellipse, centred, tilted −20°, thickness 4
half | outline_ellipse head (left/down) + thick_vline stem
quarter | filled_ellipse head (left/down) + thick_vline stem
eighth | filled_ellipse head + thick_vline stem + bezier_flag
double_eighth | Two filled_ellipse heads + two thick_vline stems + filled_rect beam
sixteenth | Two filled_ellipse heads + two thick_vline stems + two filled_rect beams

After build_sprites() completes, all intermediate bytearrays are deleted and gc.collect() is called to recover memory before the metronome palette and label objects are allocated.

# 5. Lessons Learned by Revision

## 5.1 SMDv5a — Charger Integration

- MCP73831T solder bridge (5.2 Ω, +5V to GND) prevented QT Py from booting. Always check for bridges under small IC packages using multimeter on 200 Ω resistance range before powering.
- Decoupling capacitor C1 showed ~97 Ω (misread — was actually 100 kΩ voltage divider on wrong range). Set multimeter to 200 kΩ range when reading high-value resistors.
- Replace MCP73831T and C1 as a pair when a bridge is suspected under the IC — the capacitor may have been damaged by the over-temperature event.

## 5.2 SMDv6 — Working Reference Board

- First fully functional board. All motor, buzzer, display, and battery circuits operational.
- Motor circuit verified: SS14 D2 cathode to +3.3 V, anode to Q2 collector/motor V− junction.
- Establish this board as the gold-standard reference for all future comparisons.

## 5.3 SMDv7 — B.Cu Mirror Over-Correction

- CRITICAL LESSON: Two-terminal B.Cu components (diodes, motors) do NOT automatically require mirror correction. Only SOT-23/SOT-23-5 packages have asymmetric pin layouts that need individual pin-swap verification.
- Swapping D2 (SS14) and M1 (motor) orientation to 'correct' for B.Cu mirror was an error. The motor ran constantly from power-on due to reversed flyback diode polarity.
- Always verify B.Cu two-terminal components against schematic net names, not a blanket rule.

## 5.4 SMDv8 — Battery, Silkscreen, and Button Issues

Battery Contact (Bare Wires in Unsoldered Through-Hole Pads)

- Through-hole pads without solder only make electrical contact on one side of the board. Bare battery wires inserted into unsoldered pads make intermittent or no contact.
- Resolution: Always solder both the top AND bottom of each through-hole pad before connecting wires. Alternatively, solder the wire while it is inserted to ensure contact on both sides.

Silkscreen Does Not Update with Net Swaps

- When net assignments were swapped for D3 in the schematic (rotating 180° to correct orientation), the silkscreen cathode marker did NOT update automatically.
- The silkscreen showed the ORIGINAL cathode marker position even after the schematic change.
- This caused confusion about which way to orient the diode on the physical board.
- ALWAYS verify component orientation against: (1) schematic net names, (2) KiCad 3D viewer. Do NOT rely on silkscreen when nets have been swapped.

Button Actuator Failure

- SKSCPCE010 actuators are very small (~1.5 mm) and close to the board surface. Prolonged heat exposure during soldering caused one actuator to melt/deform.
- Use low dwell time and appropriate temperature when soldering near plastic actuator components.
- Side-actuated SMD buttons cannot protrude past the display bezel (5 mm overhang on three sides). Top-actuated buttons with case-integrated pushers are the correct solution.

Stack Thickness Achievement

- 11.30 mm total stack thickness achieved with SMDv8. This is a viable wearable form factor.

Motor Runs Constantly — Residual Hardware Issue

- The SMDv8 physical board has the motor running constantly on power-up and in all modes.
- Root cause: this physical board unit has a fabrication/assembly issue (likely from the SMDv7 over-correction era). The SMDv8 schematic is correct.
- Next board revision should resolve this — the schematic has been verified and D2/M1 are correctly oriented.

## 5.5 Multimeter Protocol

Always specify the exact multimeter setting when testing:

Test | Mode | Range
Continuity / short check | Continuity (beep) | Continuity symbol
Low resistance (bridges, coils) | Resistance (Ω) | 200 Ω
Medium resistance (transistor base R) | Resistance (Ω) | 2 kΩ
High resistance (voltage dividers 100 kΩ) | Resistance (Ω) | 200 kΩ
Diode forward voltage | Diode (triangle symbol) | —
DC voltage (USB, battery) | DC Voltage (V) | 20 V DC
Low DC voltage (3.3 V rail) | DC Voltage (V) | 20 V DC

# 6. Hardware Roadmap

Item | Status | Notes
Vibration motor circuit | ✓ Verified in schematic | D2 and M1 reverted to SMDv6 orientation; next board should be correct
MBR120 D3 orientation | ✓ Verified working | Board powers from battery with current 180° orientation; silkscreen does not match — known issue
Button solution | In progress | Returning to top-actuated SMD; case-integrated angled pushers to be designed in TinkerCAD
Battery solder pads | Action required | Solder both top and bottom of through-hole battery pads before connecting wires
Case design | In progress | TinkerCAD; 5 mm display overhang on 3 sides; button pusher integration needed; Cura for slicing
Stack thickness | ✓ Achieved | 11.30 mm with SMDv8
Code — clock, metro, tuner | ✓ Complete | All three modes functional on working hardware

# 7. Quick Reference

## 7.1 Boot Sequence (from power-on)

- Clock mode is always the first mode on boot
- Time defaults to 12:00 — set with BOOT button (cycles field) and A2 (increments value)
- Advance through HOUR then MIN fields; watch face updates live

## 7.2 Mode Cycle

Hold both buttons for 0.3 s → release → advances to next mode: Clock → Metro → Tuner → Clock

## 7.3 Key Constants (code.py)

Constant | Value | Purpose
MOTOR_STRENGTH | 49151 | Motor PWM duty cycle (75%)
BUZZER_DUTY | 32768 | Buzzer duty cycle (50% square wave)
BPM_MIN / BPM_MAX | 40 / 250 | Metronome BPM limits
BPM_STEP | 5 | BPM increment/decrement per button press
BOTH_HOLD_S | 0.3 | Seconds to hold both buttons for mode switch
LONG_PRESS_S | 0.8 | Seconds for long-press (time sig or mute toggle)
DIM_AFTER_S | 300 | Seconds of inactivity before display dims
BATT_CHECK_S | 60 | Battery voltage check interval (seconds)
CHARGE_V | 4.3 | Voltage above which battery is considered charging
REFRESH_FLOOR | 0.065 | Minimum frame period (seconds) for metro animation
TUNER_ON_S | 3.0 | Tuner tone duration (seconds)
TUNER_FLASH_S | 0.4 | Tuner visual flash duration (seconds)

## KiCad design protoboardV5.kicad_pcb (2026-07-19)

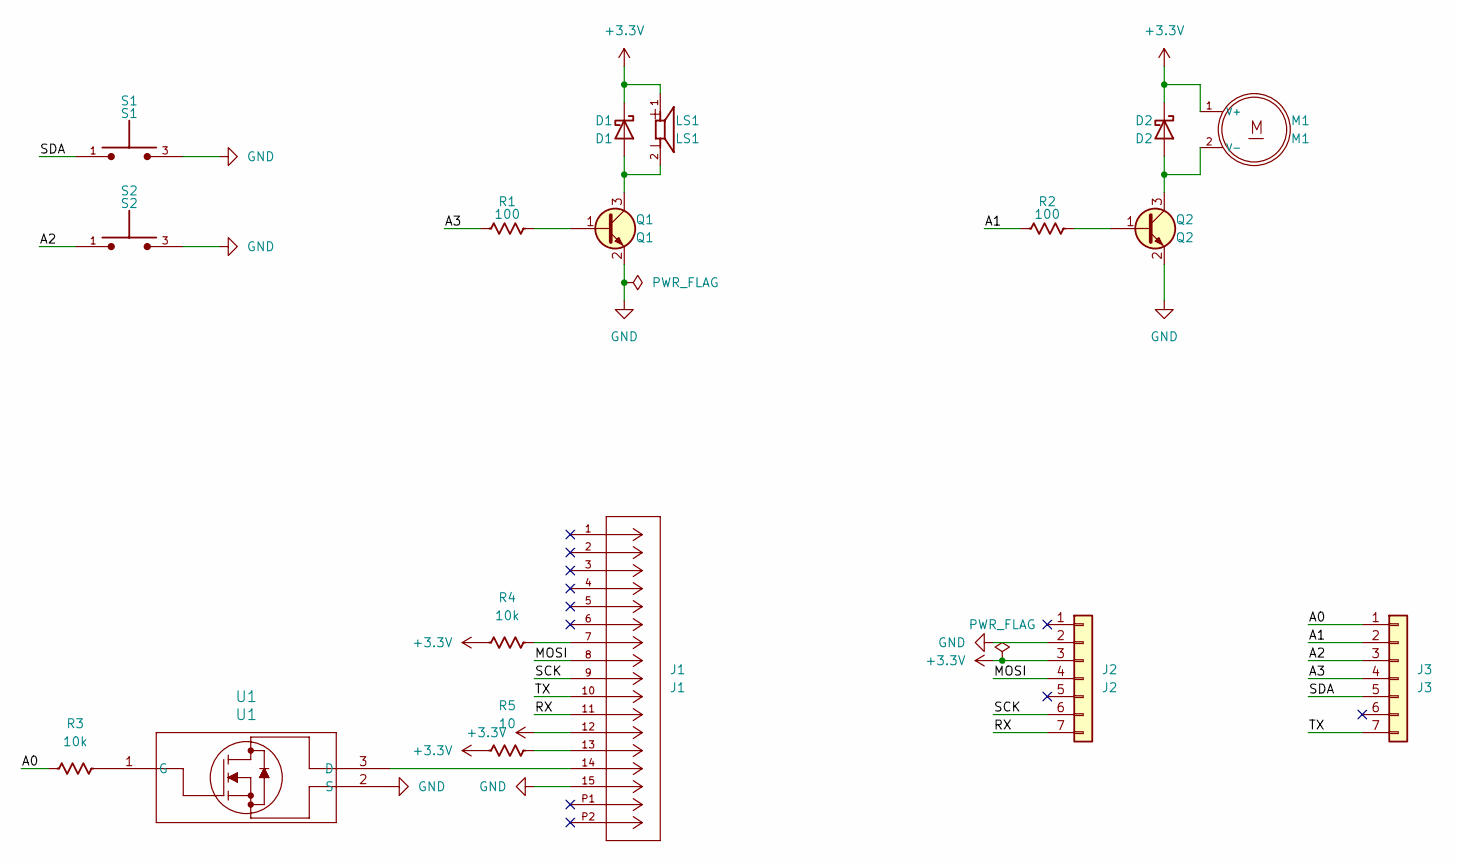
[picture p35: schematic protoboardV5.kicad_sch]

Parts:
D1: D1; D_SMA
D2: D2; D_SMA
J1: J1; CON_5051101592_MOL; MANUFACTURER_PART_NUMBER 5051101592
J2: J2; PinSocket_1x07_P2.54mm_Vertical
J3: J3; PinSocket_1x07_P2.54mm_Vertical
LS1: LS1; CUI_CSS-0575A-SMT
M1: M1; XDCR_C0720B001F
Q1: Q1; SOT-23
Q2: Q2; SOT-23
R1, R2: 100; R_0805_2012Metric
R3, R4: 10k; R_0805_2012Metric
R5: 10; R_0805_2012Metric
S1: S1; SW_SKRPABE010
S2: S2; SW_SKRPABE010
U1: U1; SOT-23_3L_ONS

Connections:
+3.3V: D1.1 (K), D2.1 (K), J1.12, J2.3, LS1.1, M1.1 (V+), R4.1, R5.1
/A0: J3.1, R3.1
/A1: J3.2, R2.1
/A2: J3.3, S2.1, S2.2
/A3: J3.4, R1.1
/MOSI: J1.8, J2.4
/RX: J1.11, J2.7
/SCK: J1.9, J2.6
/SDA: J3.5, S1.1, S1.2
/TX: J1.10, J3.7
GND: J1.15, J2.2, Q1.2 (E), Q2.2 (E), S1.3, S1.4, S2.3, S2.4, U1.2 (S)
unnamed: D1.2 (A), LS1.2, Q1.3 (C)
unnamed: D2.2 (A), M1.2 (V-), Q2.3 (C)
unnamed: J1.7, R4.2
unnamed: J1.13, R5.2
unnamed: Q1.1 (B), R1.2
unnamed: Q2.1 (B), R2.2
unnamed: J1.14, U1.3 (D)
unnamed: R3.2, U1.1 (G)

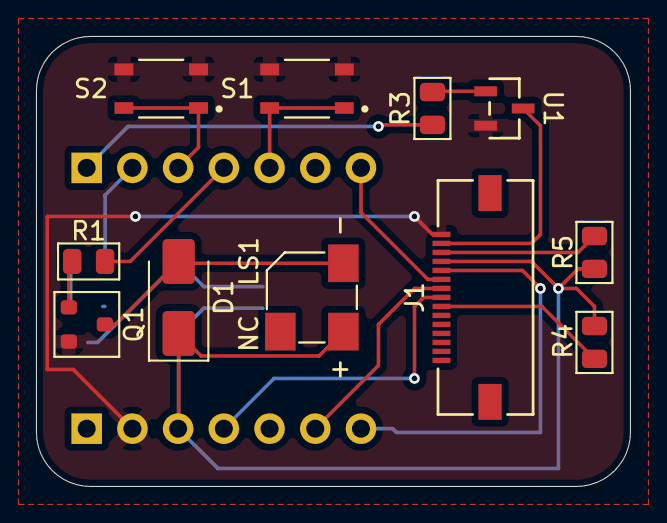
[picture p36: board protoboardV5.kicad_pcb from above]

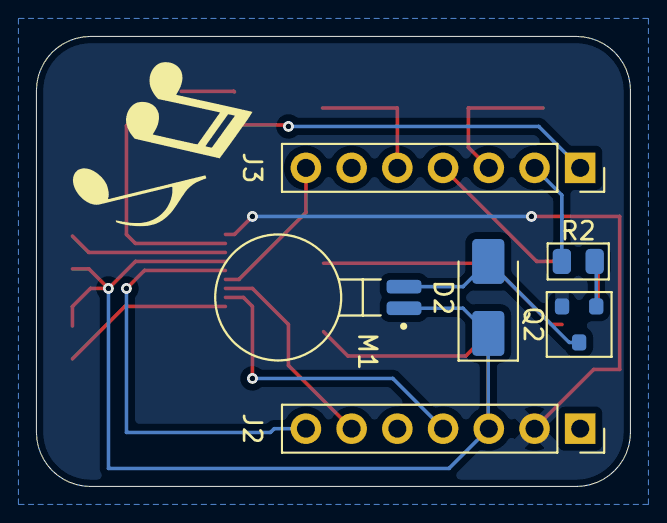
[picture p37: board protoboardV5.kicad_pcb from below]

Board: 2 copper layers, 33.0 x 25.0 mm, 17 parts (6 on the bottom side), 19 nets.

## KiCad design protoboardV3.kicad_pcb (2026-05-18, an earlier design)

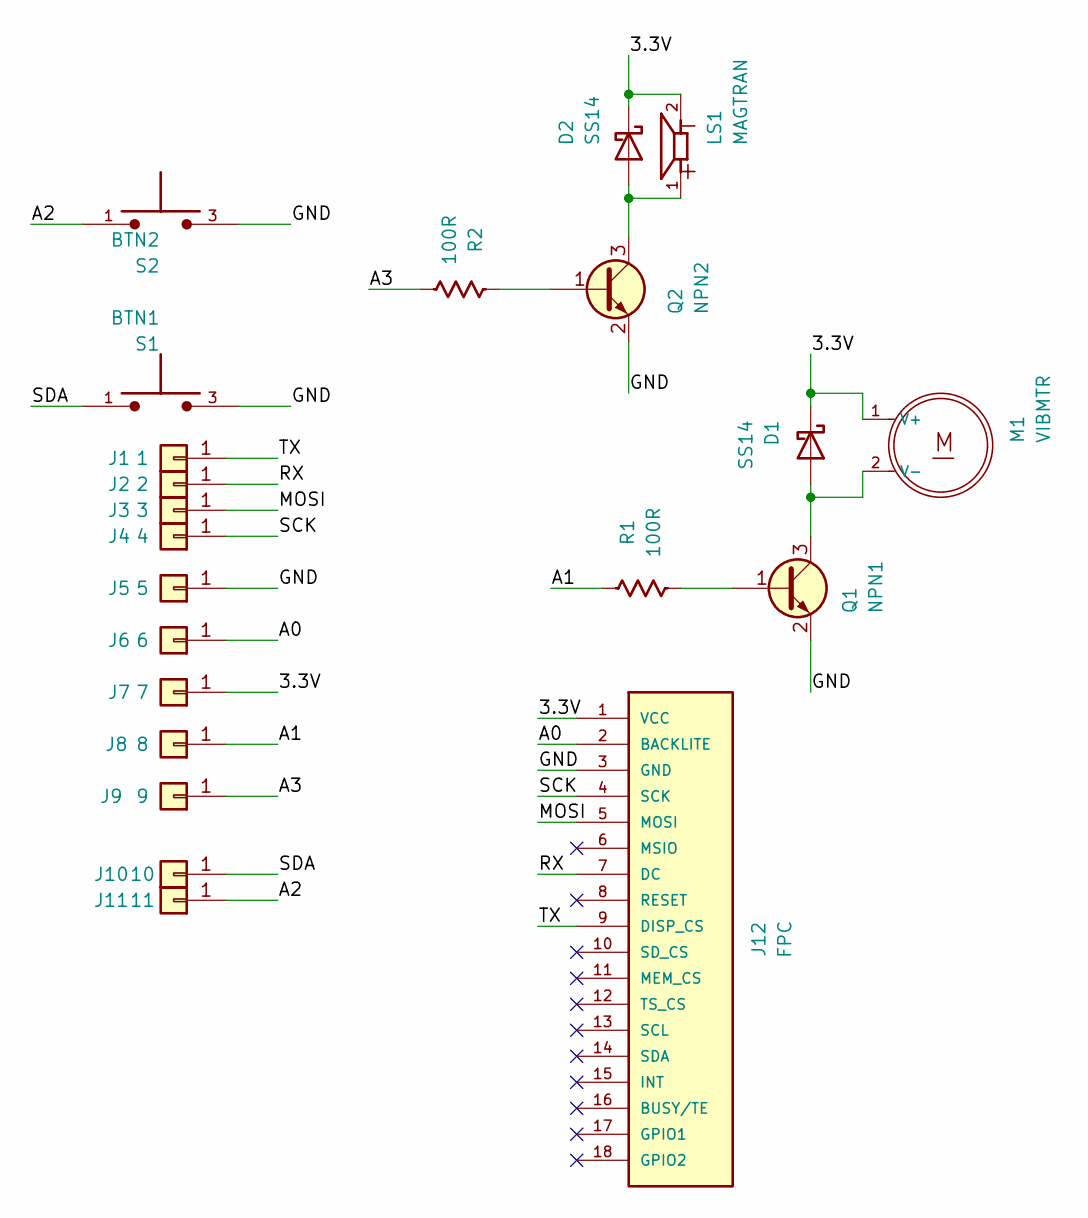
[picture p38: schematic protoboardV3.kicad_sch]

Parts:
D1, D2: SS14; D_SMA
J1: 1; 1x01_P2.54mm
J2: 2; 1x01_P2.54mm
J3: 3; 1x01_P2.54mm
J4: 4; 1x01_P2.54mm
J5: 5; 1x01_P2.54mm
J6: 6; 1x01_P2.54mm
J7: 7; 1x01_P2.54mm
J8: 8; 1x01_P2.54mm
J9: 9; 1x01_P2.54mm
J10: 10; 1x01_P2.54mm
J11: 11; 1x01_P2.54mm
J12: FPC; MOLEX_503480-1800; PARTREV J
LS1: MAGTRAN; CUI_CSS-0575A-SMT
M1: VIBMTR; XDCR_C0720B001F
Q1: NPN1; SOT-23
Q2: NPN2; SOT-23
R1, R2: 100R; R_0805_2012Metric
S1: BTN1; SW_SKRPABE010
S2: BTN2; SW_SKRPABE010

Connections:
/3.3V: D1.1 (K), D2.1 (K), J7.1 (Pin_1_1), J12.1 (VCC), LS1.2, M1.1 (V+)
/A0: J6.1 (Pin_1_1), J12.2 (BACKLITE)
/A1: J8.1 (Pin_1_1), R1.1
/A2: J11.1 (Pin_1_1), S2.1, S2.2
/A3: J9.1 (Pin_1_1), R2.1
/GND: J5.1 (Pin_1_1), J12.3 (GND), Q1.2 (E), Q2.2 (E), S1.3, S1.4, S2.3, S2.4
/MOSI: J3.1 (Pin_1_1), J12.5 (MOSI)
/RX: J2.1 (Pin_1_1), J12.7 (DC)
/SCK: J4.1 (Pin_1_1), J12.4 (SCK)
/SDA: J10.1 (Pin_1_1), S1.1, S1.2
/TX: J1.1 (Pin_1_1), J12.9 (DISP_CS)
unnamed: D1.2 (A), M1.2 (V-), Q1.3 (C)
unnamed: D2.2 (A), LS1.1, Q2.3 (C)
unnamed: Q1.1 (B), R1.2
unnamed: Q2.1 (B), R2.2

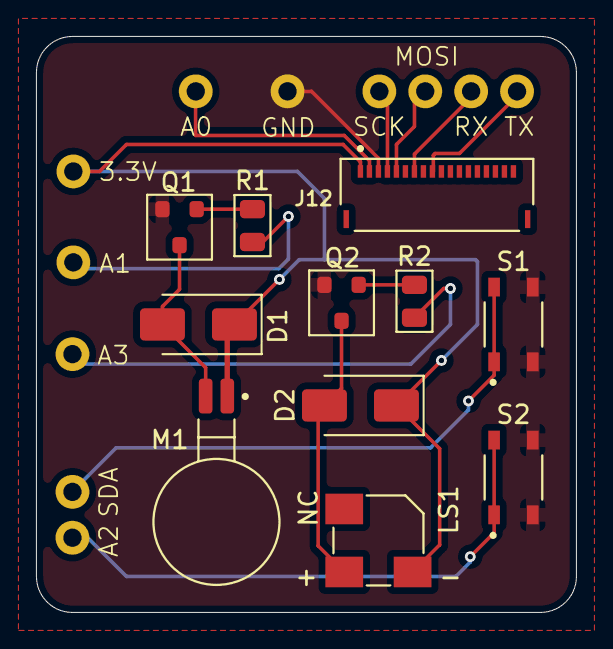
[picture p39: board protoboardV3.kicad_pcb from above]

Board: 2 copper layers, 30.0 x 32.0 mm, 22 parts (0 on the bottom side), 15 nets.

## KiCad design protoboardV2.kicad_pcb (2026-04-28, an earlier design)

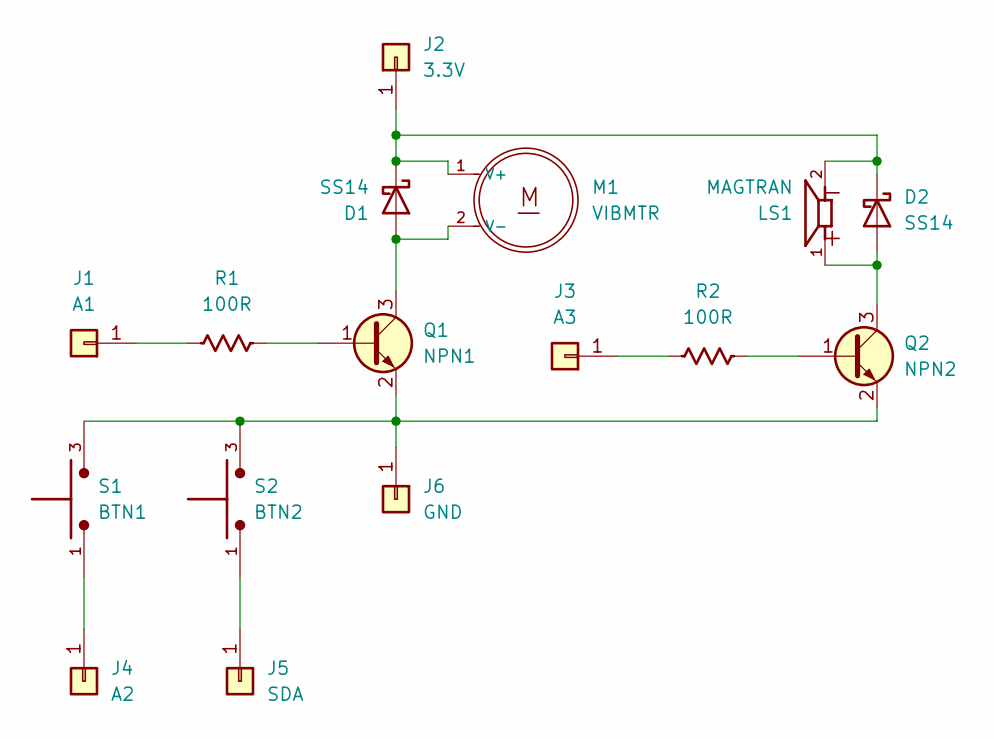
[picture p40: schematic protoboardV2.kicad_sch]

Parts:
D1, D2: SS14; D_SMA
J1: A1; Pin_D1.0mm_L10.0mm_LooseFit
J2: 3.3V; Pin_D1.0mm_L10.0mm_LooseFit
J3: A3; Pin_D1.0mm_L10.0mm_LooseFit
J4: A2; Pin_D1.0mm_L10.0mm_LooseFit
J5: SDA; Pin_D1.0mm_L10.0mm_LooseFit
J6: GND; Pin_D1.0mm_L10.0mm_LooseFit
LS1: MAGTRAN; CUI_CSS-0575A-SMT
M1: VIBMTR; XDCR_C0720B001F
Q1: NPN1; SOT-23
Q2: NPN2; SOT-23
R1, R2: 100R; R_0805_2012Metric
S1: BTN1; SW_SKRPABE010
S2: BTN2; SW_SKRPABE010

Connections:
unnamed: D1.2 (A), M1.2 (V-), Q1.3 (C)
unnamed: D1.1 (K), D2.1 (K), J2.1 (Pin_1_1), LS1.2, M1.1 (V+)
unnamed: D2.2 (A), LS1.1, Q2.3 (C)
unnamed: J1.1 (Pin_1_1), R1.1
unnamed: J3.1 (Pin_1_1), R2.1
unnamed: J4.1 (Pin_1_1), S1.1, S1.2
unnamed: J5.1 (Pin_1_1), S2.1, S2.2
unnamed: J6.1 (Pin_1_1), Q1.2 (E), Q2.2 (E), S1.3, S1.4, S2.3, S2.4
unnamed: Q1.1 (B), R1.2
unnamed: Q2.1 (B), R2.2

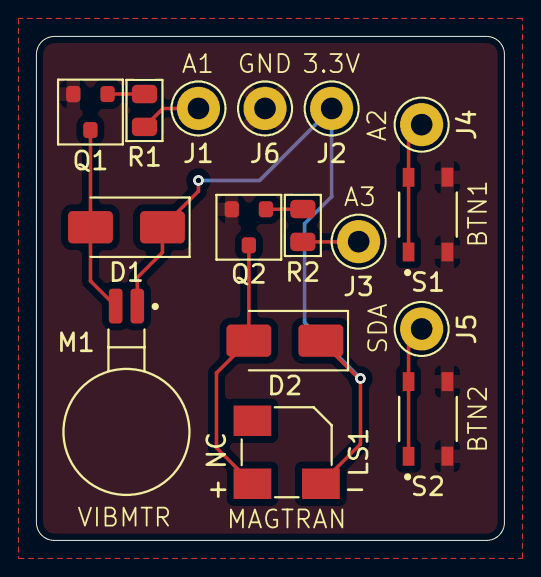
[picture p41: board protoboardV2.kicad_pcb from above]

Board: 2 copper layers, 26.0 x 28.0 mm, 16 parts (0 on the bottom side), 10 nets.

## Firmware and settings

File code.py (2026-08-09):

import gc
gc.collect()
import board,busio,displayio,fourwire,adafruit_gc9a01a
import vectorio,bitmaptools,terminalio,digitalio,rtc
import time,math
from adafruit_display_text.bitmap_label import Label
from adafruit_display_text import label
gc.collect()
displayio.release_displays()
gc.collect()
shared_bitmap=displayio.Bitmap(240,240,24)
shared_bitmap.fill(0)
import pwmio
backlight=pwmio.PWMOut(board.A0,frequency=1000,duty_cycle=65535)
gc.collect()
spi=busio.SPI(clock=board.SCK,MOSI=board.MOSI)
display_bus=fourwire.FourWire(spi,command=board.RX,chip_select=board.TX,reset=None,baudrate=24_000_000)
display=adafruit_gc9a01a.GC9A01A(display_bus,width=240,height=240,rotation=0,auto_refresh=False)
btn_a2=digitalio.DigitalInOut(board.A2)
btn_a2.direction=digitalio.Direction.INPUT
btn_a2.pull=digitalio.Pull.UP
btn_boot=digitalio.DigitalInOut(board.SDA)
btn_boot.direction=digitalio.Direction.INPUT
btn_boot.pull=digitalio.Pull.UP
motor=pwmio.PWMOut(board.A1,frequency=1000,duty_cycle=0)
MOTOR_STRENGTH=49151
buzzer=pwmio.PWMOut(board.A3,variable_frequency=True)
buzzer.frequency=440
BUZZER_DUTY=32768
BOTH_HOLD_S=0.3
LONG_PRESS_S=0.8
CX=120;CY=120
clock_rtc=rtc.RTC()
clock_rtc.datetime=time.struct_time((2025,1,1,12,0,0,0,-1,-1))
BPM_START=80;BPM_MIN=40;BPM_MAX=250;BPM_STEP=5
REFRESH_FLOOR=0.065
MAX_FADE=max(1,int((60.0/BPM_MIN)/REFRESH_FLOOR))
RANGES=(( 40, 59,"whole"),( 60, 79,"half"),( 80,119,"quarter"),(120,159,"eighth"),(160,199,"double_eighth"),(200,250,"sixteenth"))
GRADIENT=(( 40,(0x00,0x22,0xFF)),( 59,(0x00,0x99,0xFF)),( 60,(0x00,0xCC,0xAA)),( 79,(0x00,0xFF,0x88)),( 80,(0xFF,0xCC,0x00)),(119,(0xFF,0x77,0x00)),(120,(0xFF,0x44,0x00)),(159,(0xFF,0x00,0x44)),(160,(0xFF,0x00,0x99)),(199,(0xCC,0x00,0x00)),(200,(0xAA,0x00,0x00)),(250,(0x66,0x00,0x00)))
NUM_COLOURS=MAX_FADE+1
CLK_BG=0;CLK_GREEN=1;CLK_RED=2
COLOR_RED=0xFF2200
COLOR_CYAN=0x00FFFF;COLOR_WHITE=0xFFFFFF;COLOR_PINK_PURPLE=0xCC44AA
clock_palette=displayio.Palette(NUM_COLOURS)
clock_palette[CLK_BG]=0xFF00FF
clock_palette[CLK_GREEN]=0x00FF00
clock_palette[CLK_RED]=COLOR_RED
clock_palette.make_transparent(CLK_BG)
for _i in range(3,NUM_COLOURS):clock_palette[_i]=0x000000
metro_palette=displayio.Palette(NUM_COLOURS)
metro_palette[0]=0x000000
clock_tilegrid=displayio.TileGrid(shared_bitmap,pixel_shader=clock_palette)
metro_tilegrid=displayio.TileGrid(shared_bitmap,pixel_shader=metro_palette)
gc.collect()
BL_FULL=65535;BL_DIM=16384
DIM_AFTER_S=300;BATT_CHECK_S=60
CHARGE_V=4.3
BAT_GREEN=0x00CC44;BAT_YELLOW=0xCCAA00;BAT_RED=0xFF2200;BAT_BLUE=0x0044FF
LABEL_R=100;DOT_R=92
p_black=displayio.Palette(1);p_black[0]=0x000000
p_pink_purple=displayio.Palette(1);p_pink_purple[0]=COLOR_PINK_PURPLE
p_red_pal=displayio.Palette(1);p_red_pal[0]=COLOR_RED
dial=displayio.Group()
dial.append(vectorio.Circle(pixel_shader=p_black,radius=120,x=CX,y=CY))
for _i in range(60):
    if _i%5==0:continue
    _a=math.radians(_i*6-90)
    dial.append(vectorio.Circle(pixel_shader=p_pink_purple,radius=1,x=int(CX+DOT_R*math.cos(_a)),y=int(CY+DOT_R*math.sin(_a))))
for _i in range(1,13):
    _a=math.radians(_i*30-90)
    _l=Label(terminalio.FONT,text=str(_i),color=COLOR_CYAN,scale=2)
    _l.anchor_point=(0.5,0.5);_l.anchored_position=(int(CX+LABEL_R*math.cos(_a)),int(CY+LABEL_R*math.sin(_a)))
    dial.append(_l)
set_label=Label(terminalio.FONT,text="",color=COLOR_CYAN,scale=1)
set_label.anchor_point=(0.5,0.5);set_label.anchored_position=(CX,175)
dial.append(set_label)
gc.collect()
def hand_coords(ang,length,tail):
    a=math.radians(ang-90);ca,sa=math.cos(a),math.sin(a)
    return(int(CX-tail*ca),int(CY-tail*sa),int(CX+length*ca),int(CY+length*sa))
def draw_hand(bmp,x0,y0,x1,y1,col,hw):
    dx,dy=x1-x0,y1-y0;ln=math.sqrt(dx*dx+dy*dy)
    if ln==0:return
    px,py=-dy/ln,dx/ln
    for d in range(-hw,hw+1):
        ox,oy=int(d*px),int(d*py)
        bitmaptools.draw_line(bmp,x0+ox,y0+oy,x1+ox,y1+oy,col)
def hour_angle(h,m):return(h%12)*30+m*0.5
def minute_angle(m,s):return m*6+s*0.1
def second_angle(s):return s*6
def redraw_hands(h,m,s):
    shared_bitmap.fill(CLK_BG)
    draw_hand(shared_bitmap,*hand_coords(hour_angle(h,m),58,12),CLK_GREEN,2)
    draw_hand(shared_bitmap,*hand_coords(minute_angle(m,s),88,12),CLK_GREEN,1)
    draw_hand(shared_bitmap,*hand_coords(second_angle(s),82,12),CLK_RED,0)
clock_group=displayio.Group()
clock_group.append(dial)
clock_group.append(clock_tilegrid)
clock_group.append(vectorio.Circle(pixel_shader=p_red_pal,radius=5,x=CX,y=CY))
gc.collect()
def bpm_colour(bpm):
    bpm=max(BPM_MIN,min(BPM_MAX,bpm))
    if bpm<=GRADIENT[0][0]:r,g,b=GRADIENT[0][1];return(r<<16)|(g<<8)|b
    if bpm>=GRADIENT[-1][0]:r,g,b=GRADIENT[-1][1];return(r<<16)|(g<<8)|b
    for i in range(len(GRADIENT)-1):
        b0,c0=GRADIENT[i];b1,c1=GRADIENT[i+1]
        if b0<=bpm<=b1:
            t=(bpm-b0)/(b1-b0)
            r=int(c0[0]+t*(c1[0]-c0[0]));g=int(c0[1]+t*(c1[1]-c0[1]));b=int(c0[2]+t*(c1[2]-c0[2]))
            return(r<<16)|(g<<8)|b
    return 0xFFFFFF
def bpm_range(bpm):
    colour=bpm_colour(bpm)
    for lo,hi,name in RANGES:
        if lo<=bpm<=hi:return colour,name
    return colour,RANGES[-1][2]
def build_metro_palette(colour,fade_steps):
    r=(colour>>16)&0xFF;g=(colour>>8)&0xFF;b=colour&0xFF
    for i in range(1,fade_steps+1):
        s=i/fade_steps
        metro_palette[i]=(int(r*s)<<16)|(int(g*s)<<8)|int(b*s)
    for i in range(fade_steps+1,MAX_FADE+1):metro_palette[i]=0x000000
lbl_bpm=label.Label(terminalio.FONT,text="BPM",scale=3,color=COLOR_WHITE,background_color=0x000000,anchor_point=(1.0,0.5),anchored_position=(CX-45,CY))
lbl_num=label.Label(terminalio.FONT,text="80",scale=3,color=COLOR_WHITE,background_color=0x000000,anchor_point=(0.0,0.5),anchored_position=(CX+45,CY))
gc.collect()
import sprites as _spr;gc.collect()
SPRITE=_spr.build_sprites();del _spr;gc.collect()
def apply_bpm(bpm):
    colour,note=bpm_range(bpm);cycle=60.0/bpm;fsteps=max(1,int(cycle/REFRESH_FLOOR))
    build_metro_palette(colour,fsteps)
    lbl_num.text=str(bpm);lbl_num.color=colour;lbl_bpm.color=colour
    return cycle,fsteps,SPRITE[note]
def apply_sprite(buf,colour_idx):
    for i in range(0,len(buf),2):shared_bitmap[buf[i],buf[i+1]]=colour_idx
metro_group=displayio.Group()
metro_group.append(metro_tilegrid);metro_group.append(lbl_bpm);metro_group.append(lbl_num)
metro_silent=False
lbl_audio_mode=label.Label(terminalio.FONT,text="SOUND",scale=1,color=COLOR_CYAN,background_color=0x000000,anchor_point=(0.5,0.5),anchored_position=(CX,185))
metro_group.append(lbl_audio_mode)
TIME_SIGS=("4/4","3/4");TIME_SIG_BEATS=(4,3)
metro_ts_idx=0;metro_beat_pos=0
lbl_timesig=label.Label(terminalio.FONT,text="4/4",scale=1,color=COLOR_CYAN,background_color=0x000000,anchor_point=(0.5,0.5),anchored_position=(CX,50))
metro_group.append(lbl_timesig)
gc.collect()
def _build_tuner_group():
    global lbl_note,p_flash,p_fork
    g=displayio.Group()
    g.append(vectorio.Circle(pixel_shader=p_black,radius=120,x=CX,y=CY))
    tt=CY-40;bt=CY+16;bh=6;ht=bt+bh;hb=ht+26
    p_fork=displayio.Palette(1);p_fork[0]=COLOR_PINK_PURPLE
    g.append(vectorio.Rectangle(pixel_shader=p_fork,x=CX-8,y=tt,width=4,height=bt-tt))
    g.append(vectorio.Rectangle(pixel_shader=p_fork,x=CX+4,y=tt,width=4,height=bt-tt))
    g.append(vectorio.Rectangle(pixel_shader=p_fork,x=CX-8,y=bt,width=16,height=bh))
    g.append(vectorio.Rectangle(pixel_shader=p_fork,x=CX-3,y=ht,width=6,height=hb-ht))
    p_flash=displayio.Palette(1);p_flash[0]=0x000000
    g.append(vectorio.Rectangle(pixel_shader=p_flash,x=CX-26,y=CY-22,width=16,height=3))
    g.append(vectorio.Rectangle(pixel_shader=p_flash,x=CX-34,y=CY-9,width=22,height=3))
    g.append(vectorio.Rectangle(pixel_shader=p_flash,x=CX-26,y=CY+4,width=16,height=3))
    g.append(vectorio.Rectangle(pixel_shader=p_flash,x=CX+10,y=CY-22,width=16,height=3))
    g.append(vectorio.Rectangle(pixel_shader=p_flash,x=CX+12,y=CY-9,width=22,height=3))
    g.append(vectorio.Rectangle(pixel_shader=p_flash,x=CX+10,y=CY+4,width=16,height=3))
    lbl_note=Label(terminalio.FONT,text="E4  329Hz",color=COLOR_PINK_PURPLE,scale=2)
    lbl_note.anchor_point=(0.5,0.5);lbl_note.anchored_position=(CX,55);g.append(lbl_note)
    return g
tuner_group=_build_tuner_group();del _build_tuner_group;gc.collect()
TUNER_NOTES=(("E4",329.63),("A4",440.00),("D5",587.33),("G5",783.99),("B5",987.77),("E6",1318.51))
TUNER_ON_S=3.0
TUNER_FLASH_S=0.4
tuner_note_idx=0
tuner_playing=False
tuner_next_t=0.0
tuner_strike_t=0.0
display_dimmed=False
bat_charging=False;bat_percent=0
last_batt_check=0.0
lbl_tuner_mute=label.Label(terminalio.FONT,text="STRIKE",scale=1,color=COLOR_CYAN,anchor_point=(0.5,0.5),anchored_position=(CX,185))
tuner_group.append(lbl_tuner_mute);gc.collect()
lbl_bat_clock=label.Label(terminalio.FONT,text="BAT",scale=1,color=BAT_GREEN,background_color=0x000000,anchor_point=(0.5,0.5),anchored_position=(CX,197))
lbl_bat_metro=label.Label(terminalio.FONT,text="BAT",scale=1,color=BAT_GREEN,background_color=0x000000,anchor_point=(0.5,0.5),anchored_position=(CX,205))
lbl_bat_tuner=label.Label(terminalio.FONT,text="BAT",scale=1,color=BAT_GREEN,anchor_point=(0.5,0.5),anchored_position=(CX,200))
clock_group.append(lbl_bat_clock)
metro_group.append(lbl_bat_metro)
tuner_group.append(lbl_bat_tuner)
gc.collect()
def both_held():return(not btn_a2.value)and(not btn_boot.value)
def wait_release_both():
    while(not btn_a2.value)or(not btn_boot.value):time.sleep(0.02)
def check_mode_switch():
    t=time.monotonic()
    while both_held():
        if time.monotonic()-t>=BOTH_HOLD_S:wait_release_both();return True
        time.sleep(0.02)
    return False
def wait_release(btn):
    while not btn.value:time.sleep(0.05)
def vibrate(ms):
    motor.duty_cycle=MOTOR_STRENGTH;time.sleep(ms/1000);motor.duty_cycle=0
def tone(freq,ms):
    buzzer.frequency=freq;buzzer.duty_cycle=BUZZER_DUTY
    time.sleep(ms/1000);buzzer.duty_cycle=0
def set_backlight(duty):backlight.duty_cycle=duty
def register_interaction():
    global last_interaction,display_dimmed
    last_interaction=time.monotonic()
    if display_dimmed:set_backlight(BL_FULL);display_dimmed=False
def is_waking():return display_dimmed
def check_dim_timeout():
    global display_dimmed
    if not display_dimmed and time.monotonic()-last_interaction>=DIM_AFTER_S:
        set_backlight(BL_DIM);display_dimmed=True
def read_battery():
    global btn_a2
    import analogio
    btn_a2.deinit()
    adc=analogio.AnalogIn(board.A2);raw=adc.value;adc.deinit()
    btn_a2=digitalio.DigitalInOut(board.A2)
    btn_a2.direction=digitalio.Direction.INPUT;btn_a2.pull=digitalio.Pull.UP
    return(raw/65535)*3.3*2.0
def bat_colour(pct):
    if pct>=50:return BAT_GREEN
    if pct>=25:return BAT_YELLOW
    return BAT_RED
def update_bat_labels():
    c=BAT_BLUE if bat_charging else bat_colour(bat_percent)
    lbl_bat_clock.color=c;lbl_bat_metro.color=c;lbl_bat_tuner.color=c
MODE_CLOCK=0;MODE_METRO=1;MODE_TUNER=2;NUM_MODES=3
mode=MODE_CLOCK
def enter_clock():
    buzzer.duty_cycle=0
    t=time.localtime();redraw_hands(t.tm_hour,t.tm_min,t.tm_sec)
    display.root_group=clock_group;display.refresh()
def enter_metro():
    buzzer.duty_cycle=0
    shared_bitmap.fill(0);display.root_group=metro_group;display.refresh()
def enter_tuner():
    global tuner_playing,tuner_next_t,tuner_strike_t
    buzzer.duty_cycle=0;tuner_playing=False;tuner_strike_t=0.0
    p_flash[0]=0x000000;p_fork[0]=COLOR_PINK_PURPLE;lbl_tuner_mute.text="STRIKE"
    display.root_group=tuner_group;display.refresh()
def advance_mode():
    global mode,beat_start,last_beat_t,beat_count,step,btn_a2_prev,btn_boot_prev,metro_beat_pos
    mode=(mode+1)%NUM_MODES
    if mode==MODE_CLOCK:
        global last_sec;last_sec=-1;enter_clock()
    elif mode==MODE_METRO:
        beat_start=time.monotonic()+0.15;last_beat_t=beat_start
        beat_count=0;step=FADE_STEPS;metro_beat_pos=0
        btn_a2_prev=True;btn_boot_prev=True;enter_metro()
    elif mode==MODE_TUNER:
        btn_a2_prev=True;btn_boot_prev=True;enter_tuner()
FIELDS=("HOUR","MIN")
def run_time_set():
    t=time.localtime();edit=[t.tm_hour,t.tm_min]
    def rd():
        shared_bitmap.fill(CLK_BG)
        draw_hand(shared_bitmap,*hand_coords(hour_angle(edit[0],edit[1]),58,12),CLK_GREEN,2)
        draw_hand(shared_bitmap,*hand_coords(minute_angle(edit[1],0),88,12),CLK_GREEN,1)
        display.refresh()
    def inc(f):
        if f==0:edit[0]=(edit[0]+1)%24
        elif f==1:edit[1]=(edit[1]+1)%60
    for f in range(len(FIELDS)):
        set_label.text=FIELDS[f];rd()
        while True:
            if both_held():set_label.text="";return False
            if not btn_boot.value:wait_release(btn_boot);break
            if not btn_a2.value:inc(f);rd();wait_release(btn_a2)
            time.sleep(0.05)
    set_label.text=""
    clock_rtc.datetime=time.struct_time((2025,1,1,edit[0],edit[1],0,0,-1,-1))
    return True
enter_clock()
last_sec=time.localtime().tm_sec
BPM=BPM_START
cycle_s,FADE_STEPS,SPR=apply_bpm(BPM)
beat_start=time.monotonic()+0.15;beat_count=0;last_beat_t=beat_start;step=FADE_STEPS
btn_a2_prev=True;btn_boot_prev=True
last_interaction=time.monotonic()
while True:
    check_dim_timeout()
    update_bat_labels()
    now_t=time.monotonic()
    if now_t-last_batt_check>=BATT_CHECK_S:
        voltage=read_battery();bat_charging=voltage>=CHARGE_V
        raw_pct=int((min(voltage,4.2)-3.0)/(4.2-3.0)*100)
        bat_percent=max(0,min(100,raw_pct))
        last_batt_check=now_t;gc.collect()
    if both_held():
        if check_mode_switch():advance_mode();continue
    if mode==MODE_CLOCK:
        if not btn_a2.value:
            if is_waking():register_interaction()
            while not btn_a2.value:time.sleep(0.01)
        if not btn_boot.value:
            if is_waking():
                register_interaction()
                while not btn_boot.value:time.sleep(0.01)
                continue
            register_interaction()
            wait_release(btn_boot);result=run_time_set()
            if not result:
                if check_mode_switch():advance_mode()
            else:
                t=time.localtime();redraw_hands(t.tm_hour,t.tm_min,t.tm_sec)
                last_sec=t.tm_sec;display.refresh()
            continue
        t=time.localtime()
        if t.tm_sec!=last_sec:
            redraw_hands(t.tm_hour,t.tm_min,t.tm_sec);last_sec=t.tm_sec;display.refresh()
        else:
            time.sleep(0.01)
    elif mode==MODE_METRO:
        a2_now=btn_a2.value
        if btn_a2_prev and not a2_now:
            if is_waking():register_interaction();btn_a2_prev=btn_a2.value
            elif not both_held():
                a2_press_t=time.monotonic()
                while not btn_a2.value:
                    if both_held():break
                    if time.monotonic()-a2_press_t>=LONG_PRESS_S:
                        metro_ts_idx=(metro_ts_idx+1)%len(TIME_SIGS)
                        lbl_timesig.text=TIME_SIGS[metro_ts_idx];metro_beat_pos=0
                        step=FADE_STEPS
                        wait_release(btn_a2);a2_now=btn_a2.value
                        beat_start=time.monotonic()+0.15;break
                    time.sleep(0.02)
                else:
                    if BPM<BPM_MAX:
                        old_spr=SPR;BPM=min(BPM_MAX,BPM+BPM_STEP)
                        cycle_s,FADE_STEPS,SPR=apply_bpm(BPM);apply_sprite(old_spr,0)
                        beat_start=time.monotonic()+0.15;step=FADE_STEPS;gc.collect()
        btn_a2_prev=a2_now
        boot_now=btn_boot.value
        if btn_boot_prev and not boot_now:
            if is_waking():register_interaction();boot_now=btn_boot.value
            elif not both_held():
                boot_press_t=time.monotonic()
                while not btn_boot.value:
                    if both_held():break
                    if time.monotonic()-boot_press_t>=LONG_PRESS_S:
                        metro_silent=not metro_silent
                        lbl_audio_mode.text="SILENT" if metro_silent else "SOUND"
                        wait_release(btn_boot);boot_now=btn_boot.value
                        beat_start=time.monotonic()+0.15;step=FADE_STEPS;break
                    time.sleep(0.02)
                else:
                    if BPM>BPM_MIN:
                        old_spr=SPR;BPM=max(BPM_MIN,BPM-BPM_STEP)
                        cycle_s,FADE_STEPS,SPR=apply_bpm(BPM);apply_sprite(old_spr,0)
                        beat_start=time.monotonic()+0.15;step=FADE_STEPS;gc.collect()
        btn_boot_prev=boot_now
        apply_sprite(SPR,step);display.refresh()
        step_num=FADE_STEPS-step
        target_time=beat_start+(step_num+1)/(FADE_STEPS+1)*cycle_s
        remainder=target_time-time.monotonic()
        if remainder>0:time.sleep(remainder)
        step-=1
        if step<0:
            step=FADE_STEPS;beat_start+=cycle_s;beat_count+=1
            is_downbeat=(metro_beat_pos==0)
            if not metro_silent:
                tone(880 if is_downbeat else 660,60)
            else:
                vibrate(80 if is_downbeat else 50)
            metro_beat_pos=(metro_beat_pos+1)%TIME_SIG_BEATS[metro_ts_idx]
            now=time.monotonic();last_beat_t=now
            if beat_count%8==0:gc.collect()
    elif mode==MODE_TUNER:
        now=time.monotonic()
        if tuner_playing and now>=tuner_next_t:
            buzzer.duty_cycle=0;tuner_playing=False
            lbl_tuner_mute.text="STRIKE";display.refresh()
        if tuner_strike_t>0.0 and now-tuner_strike_t>=TUNER_FLASH_S:
            p_flash[0]=0x000000;p_fork[0]=COLOR_PINK_PURPLE;tuner_strike_t=0.0;display.refresh()
        a2_now=btn_a2.value
        if btn_a2_prev and not a2_now:
            if is_waking():register_interaction();a2_now=btn_a2.value
            elif not both_held() and not tuner_playing:
                while not btn_a2.value:
                    if both_held():break
                    time.sleep(0.02)
                else:
                    tuner_note_idx=(tuner_note_idx+1)%len(TUNER_NOTES)
                    name,freq=TUNER_NOTES[tuner_note_idx]
                    lbl_note.text="{:s} {:4d}Hz".format(name,int(freq))
                    register_interaction();display.refresh()
                a2_now=btn_a2.value
        btn_a2_prev=a2_now
        boot_now=btn_boot.value
        if btn_boot_prev and not boot_now:
            if is_waking():register_interaction();boot_now=btn_boot.value
            elif not both_held():
                while not btn_boot.value:
                    if both_held():break
                    time.sleep(0.02)
                else:
                    register_interaction()
                    if tuner_playing:
                        buzzer.duty_cycle=0;tuner_playing=False
                        p_flash[0]=0x000000;p_fork[0]=COLOR_PINK_PURPLE;tuner_strike_t=0.0
                        lbl_tuner_mute.text="STRIKE"
                    else:
                        name,freq=TUNER_NOTES[tuner_note_idx]
                        buzzer.frequency=int(freq);buzzer.duty_cycle=BUZZER_DUTY
                        tuner_playing=True;tuner_next_t=now+TUNER_ON_S
                        tuner_strike_t=now;p_flash[0]=0xFFFFFF;p_fork[0]=0xFFFFFF
                        lbl_tuner_mute.text="STOP"
                    display.refresh()
                boot_now=btn_boot.value
        btn_boot_prev=boot_now
        time.sleep(0.02)

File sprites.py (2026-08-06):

# sprites.py — note sprite pixel buffers for metronome
# Imported by code.py after shared_bitmap is allocated.
# CX/CY and WIDTH/HEIGHT are duplicated from code.py intentionally —
# this module imports independently and cannot reference code.py globals.
import math,gc
CX,CY=120,120
WIDTH,HEIGHT=240,240

def filled_ellipse(cx,cy,rx,ry,ang):
    buf=bytearray();a=math.radians(ang);ca,sa=math.cos(a),math.sin(a);rx2,ry2=rx*rx,ry*ry
    for dy in range(-ry-2,ry+3):
        for dx in range(-rx-2,rx+3):
            xr=dx*ca+dy*sa;yr=-dx*sa+dy*ca
            if xr*xr*ry2+yr*yr*rx2<=rx2*ry2:
                px,py=cx+dx,cy+dy
                if 0<=px<WIDTH and 0<=py<HEIGHT:buf.append(px);buf.append(py)
    return buf

def outline_ellipse(cx,cy,rx,ry,ang,thickness=3):
    buf=bytearray();a=math.radians(ang);ca,sa=math.cos(a),math.sin(a);rx2,ry2=rx*rx,ry*ry
    irx,iry=max(1,rx-thickness),max(1,ry-thickness);irx2,iry2=irx*irx,iry*iry
    for dy in range(-ry-2,ry+3):
        for dx in range(-rx-2,rx+3):
            xr=dx*ca+dy*sa;yr=-dx*sa+dy*ca
            outer=xr*xr*ry2+yr*yr*rx2<=rx2*ry2;inner=xr*xr*iry2+yr*yr*irx2<=irx2*iry2
            if outer and not inner:
                px,py=cx+dx,cy+dy
                if 0<=px<WIDTH and 0<=py<HEIGHT:buf.append(px);buf.append(py)
    return buf

def thick_vline(x,y0,y1,w):
    buf=bytearray();half=w//2
    for y in range(min(y0,y1),max(y0,y1)+1):
        for dx in range(-half,half+1):
            px=x+dx
            if 0<=px<WIDTH and 0<=y<HEIGHT:buf.append(px);buf.append(y)
    return buf

def filled_rect(x,y,w,h):
    buf=bytearray()
    for dy in range(h):
        for dx in range(w):
            px,py=x+dx,y+dy
            if 0<=px<WIDTH and 0<=py<HEIGHT:buf.append(px);buf.append(py)
    return buf

def bezier_flag(x0,y0,steps=20,thickness=3):
    buf=bytearray();p0=(x0,y0);p1=(x0+22,y0+2);p2=(x0+24,y0+14);p3=(x0+14,y0+22);half=thickness//2
    for i in range(steps+1):
        t=i/steps;mt=1-t
        bx=int(mt**3*p0[0]+3*mt**2*t*p1[0]+3*mt*t**2*p2[0]+t**3*p3[0])
        by=int(mt**3*p0[1]+3*mt**2*t*p1[1]+3*mt*t**2*p2[1]+t**3*p3[1])
        for dy in range(-half,half+1):
            for dx in range(-half,half+1):
                if dx*dx+dy*dy<=half*half+1:
                    px,py=bx+dx,by+dy
                    if 0<=px<WIDTH and 0<=py<HEIGHT:buf.append(px);buf.append(py)
    return buf

def merge(*bufs):
    out=bytearray()
    for buf in bufs:out.extend(buf)
    return out

def build_sprites():
    SPRITE={}
    SPRITE["whole"]=outline_ellipse(CX,CY,20,14,-20,thickness=4);gc.collect()
    head_h=outline_ellipse(CX-12,CY+15,14,10,-20,thickness=3);stem_h=thick_vline(CX,CY+8,CY-32,4)
    SPRITE["half"]=merge(head_h,stem_h);del head_h,stem_h;gc.collect()
    head_q=filled_ellipse(CX-12,CY+15,14,10,-20);stem_q=thick_vline(CX,CY+8,CY-32,4)
    SPRITE["quarter"]=merge(head_q,stem_q);del head_q,stem_q;gc.collect()
    head_e=filled_ellipse(CX-12,CY+15,14,10,-20);stem_e=thick_vline(CX,CY+8,CY-32,4);flag_e=bezier_flag(CX,CY-32,steps=24,thickness=3)
    SPRITE["eighth"]=merge(head_e,stem_e,flag_e);del head_e,stem_e,flag_e;gc.collect()
    head_s1=filled_ellipse(CX-22,CY+15,13,9,-20);stem_s1=thick_vline(CX-11,CY+7,CY-22,4)
    head_s2=filled_ellipse(CX+12,CY+5,13,9,-20);stem_s2=thick_vline(CX+23,CY-3,CY-22,4)
    beam_s1=filled_rect(CX-11,CY-26,35,7);beam_s2=filled_rect(CX-11,CY-17,35,7)
    SPRITE["sixteenth"]=merge(head_s1,stem_s1,head_s2,stem_s2,beam_s1,beam_s2);del head_s1,stem_s1,head_s2,stem_s2,beam_s1,beam_s2;gc.collect()
    head_e1=filled_ellipse(CX-22,CY+15,13,9,-20);stem_e1=thick_vline(CX-11,CY+7,CY-22,4)
    head_e2=filled_ellipse(CX+12,CY+5,13,9,-20);stem_e2=thick_vline(CX+23,CY-3,CY-22,4);beam=filled_rect(CX-11,CY-26,35,7)
    SPRITE["double_eighth"]=merge(head_e1,stem_e1,head_e2,stem_e2,beam);del head_e1,stem_e1,head_e2,stem_e2,beam;gc.collect()
    return SPRITE
